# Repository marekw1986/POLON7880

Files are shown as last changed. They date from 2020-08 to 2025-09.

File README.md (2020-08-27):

# POLON 7880

## Overview

This is repository stores modified version of TinyBasic interpreter for 8080 based microcomputers. 
It has been customized to my homemade system, based on Polish clone of mentioned CPU - 
CEMI MCY7880. Original code has been supplemented with I/O routines supporting built-in 
peripherals.

Computer is described on my [Hackaday.io profile](https://hackaday.io/project/161333-polon-7880)

This project is still in development.

## Required tools

You need an [a86 cross assembler](https://github.com/glitchwrks/a85) to asemble this project.

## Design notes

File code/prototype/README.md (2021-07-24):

# POLON 7880

This is code of TinyBsic for prototype version of POLON 7880, wired on prototype board.

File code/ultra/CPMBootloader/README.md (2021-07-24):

# POLON 7880

This is code of TinyBsic for final version of POLON 7880, build on PCBs.

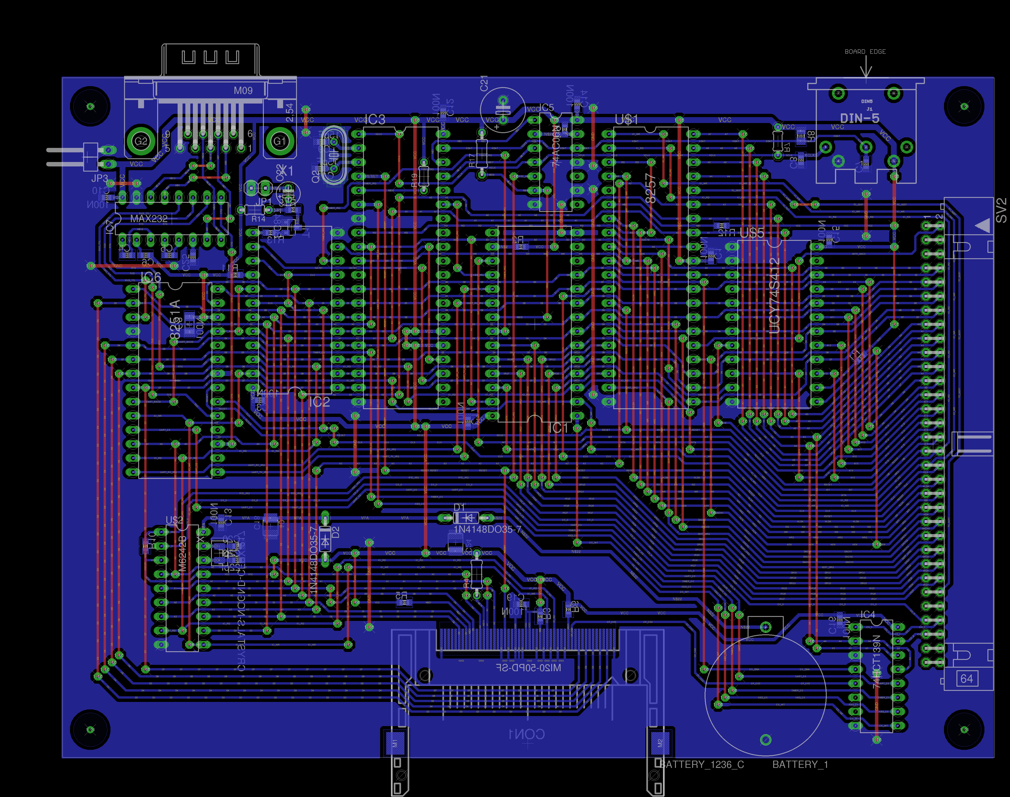
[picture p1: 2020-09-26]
hardware/io/board.png

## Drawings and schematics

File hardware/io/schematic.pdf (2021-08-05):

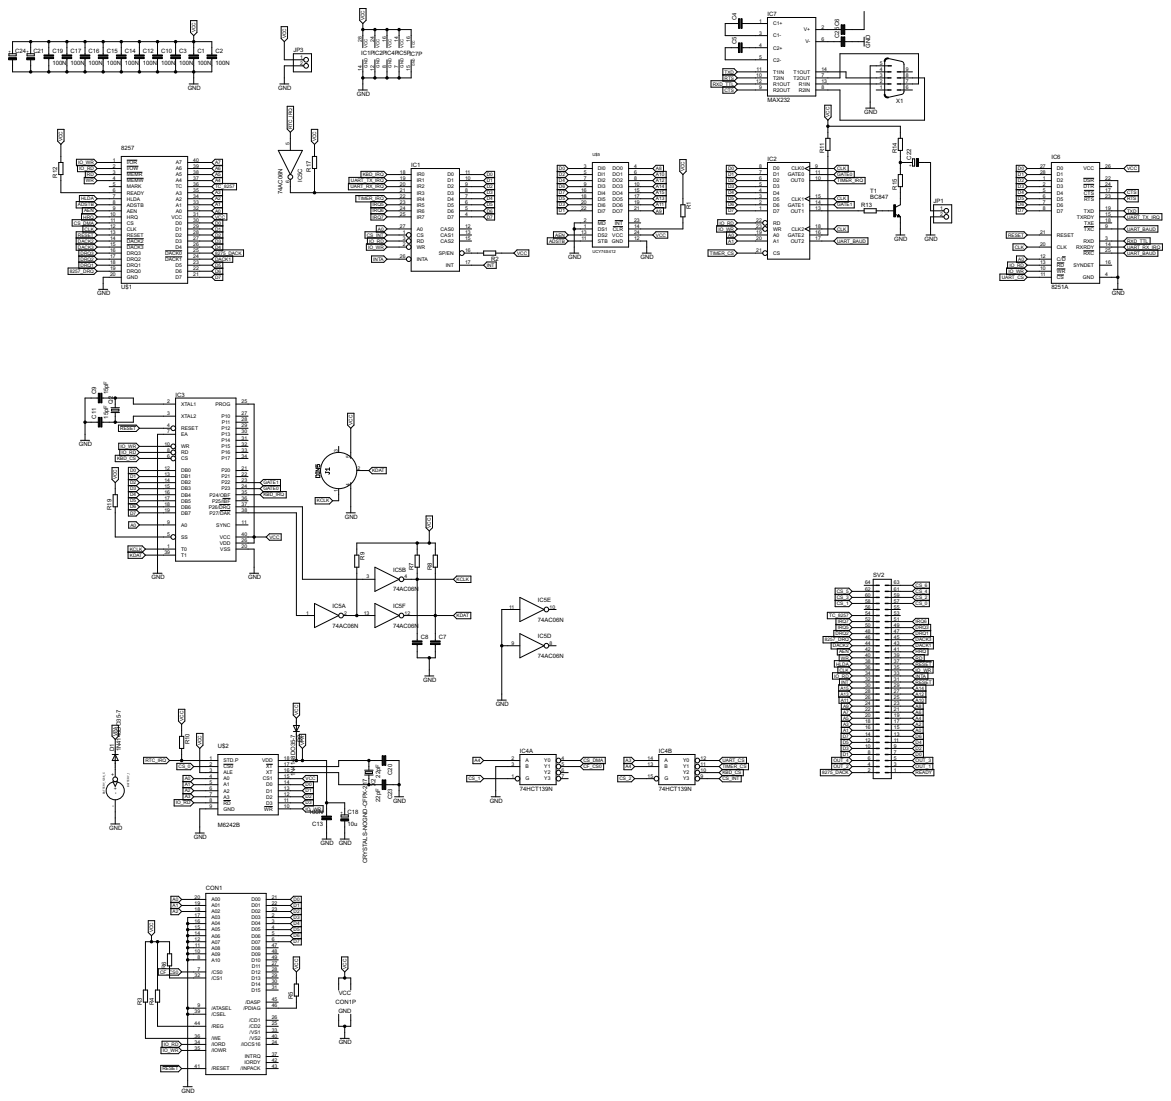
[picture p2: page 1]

8 | 49 D11
7 | 27 D12

32 | 29 D14
9 | 30 D15

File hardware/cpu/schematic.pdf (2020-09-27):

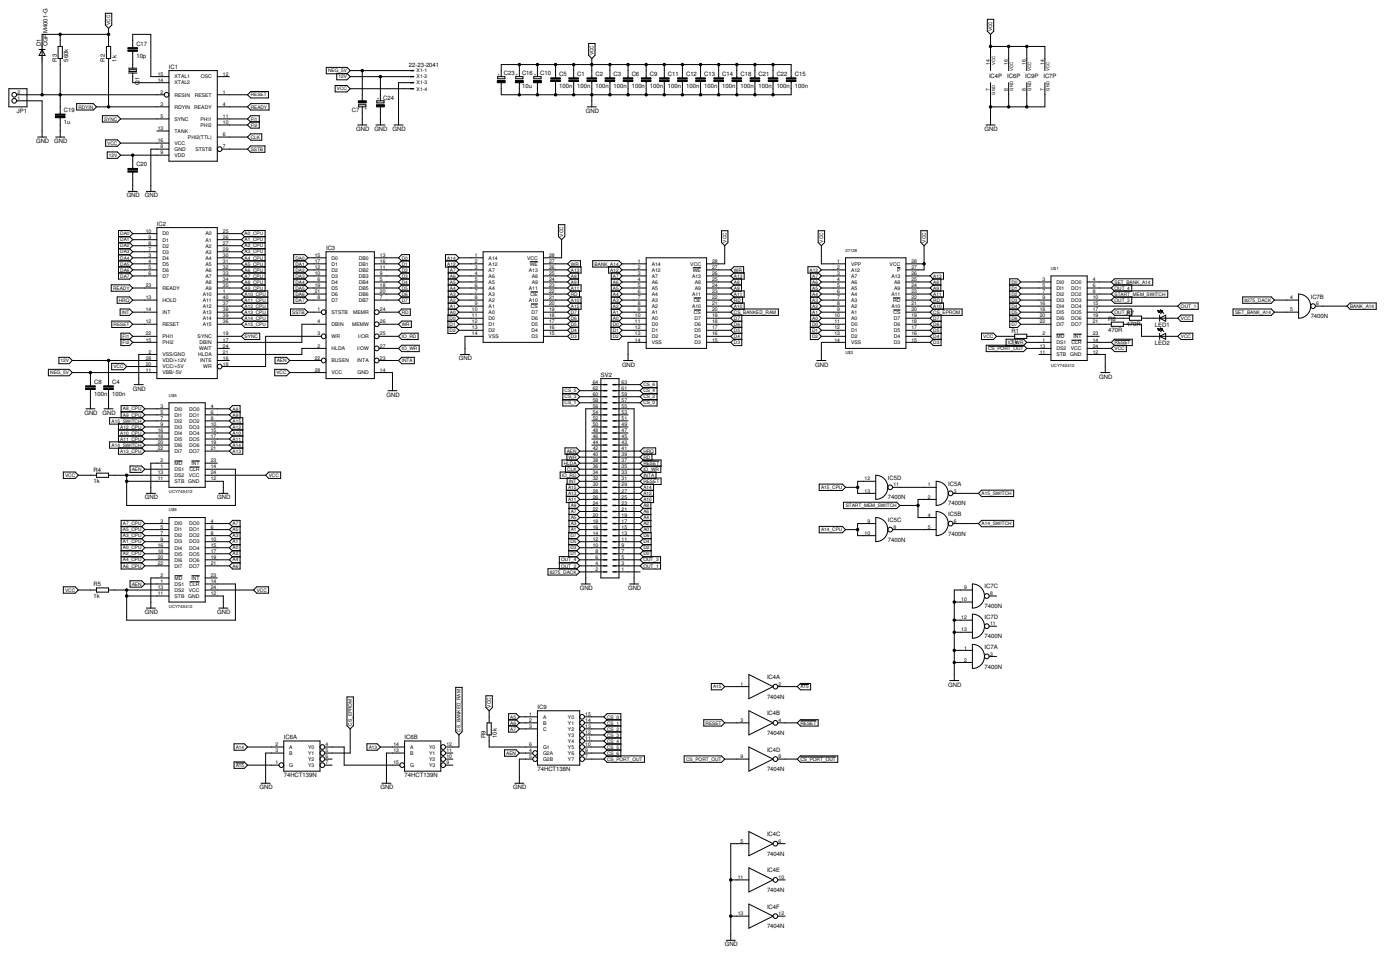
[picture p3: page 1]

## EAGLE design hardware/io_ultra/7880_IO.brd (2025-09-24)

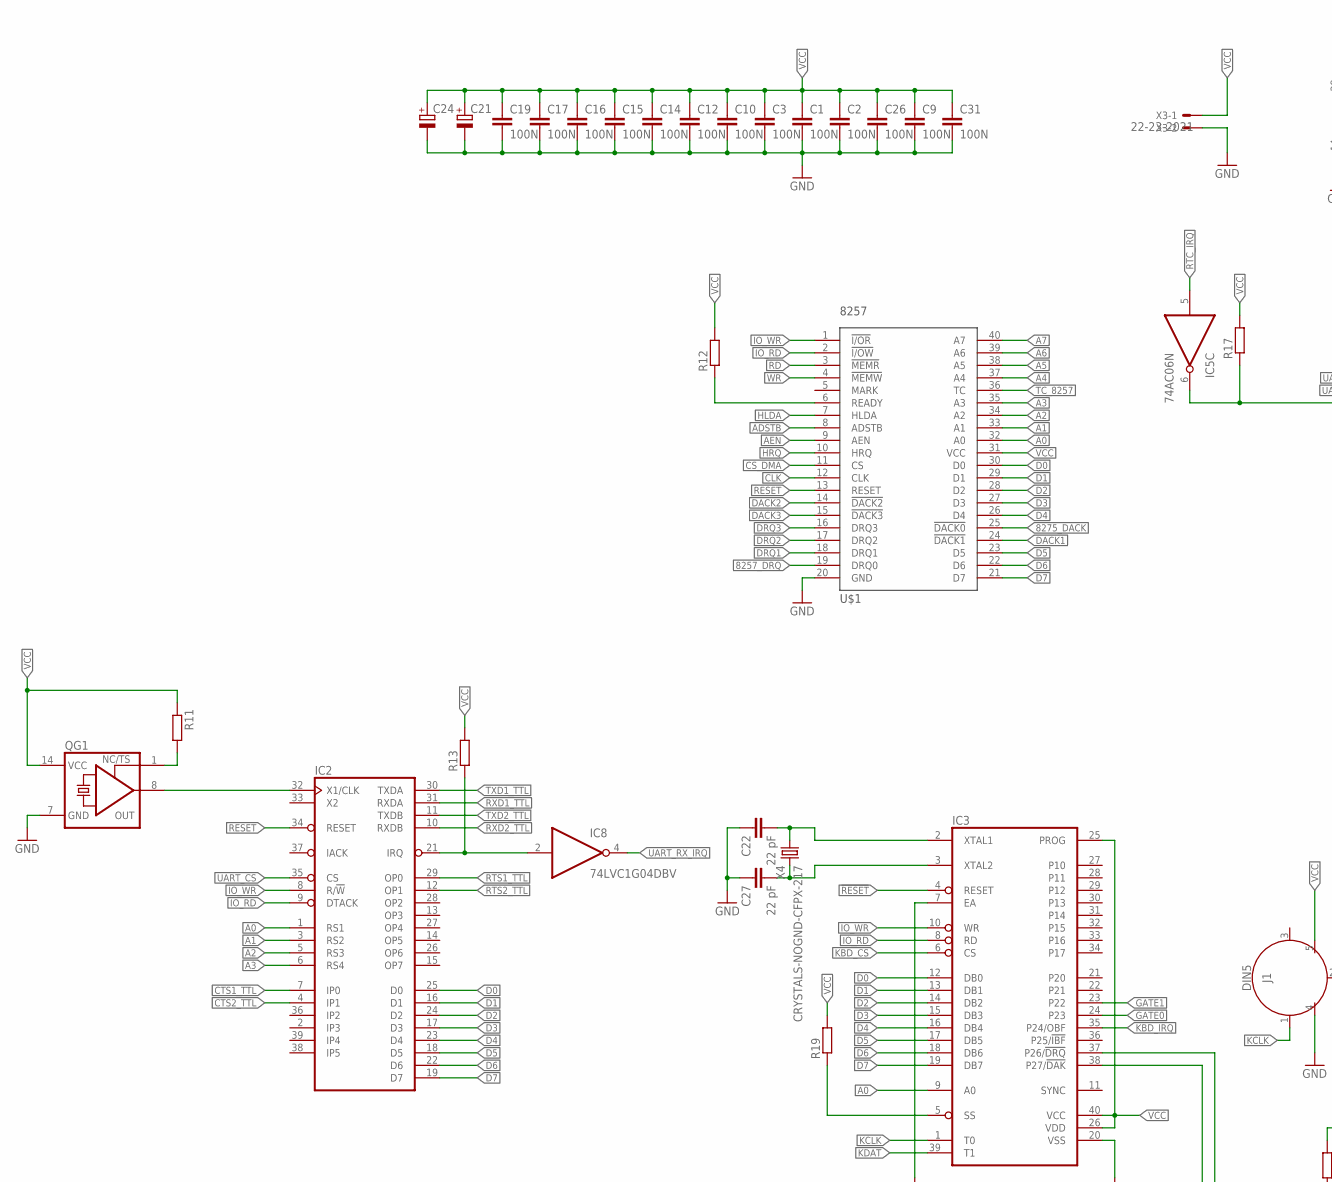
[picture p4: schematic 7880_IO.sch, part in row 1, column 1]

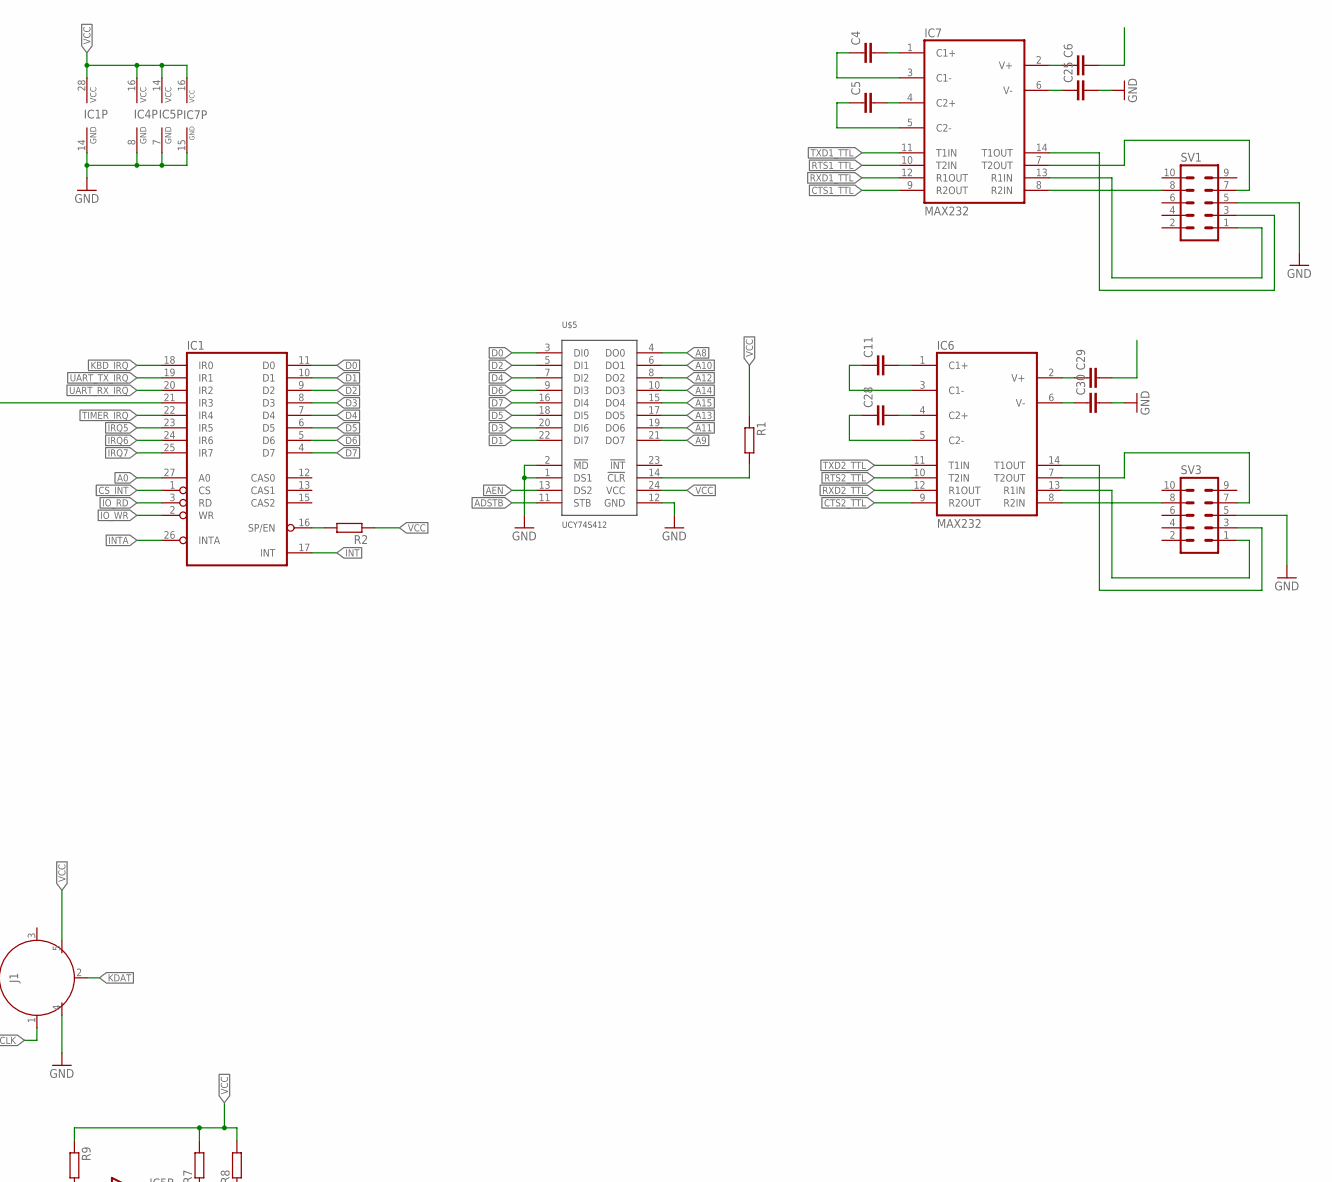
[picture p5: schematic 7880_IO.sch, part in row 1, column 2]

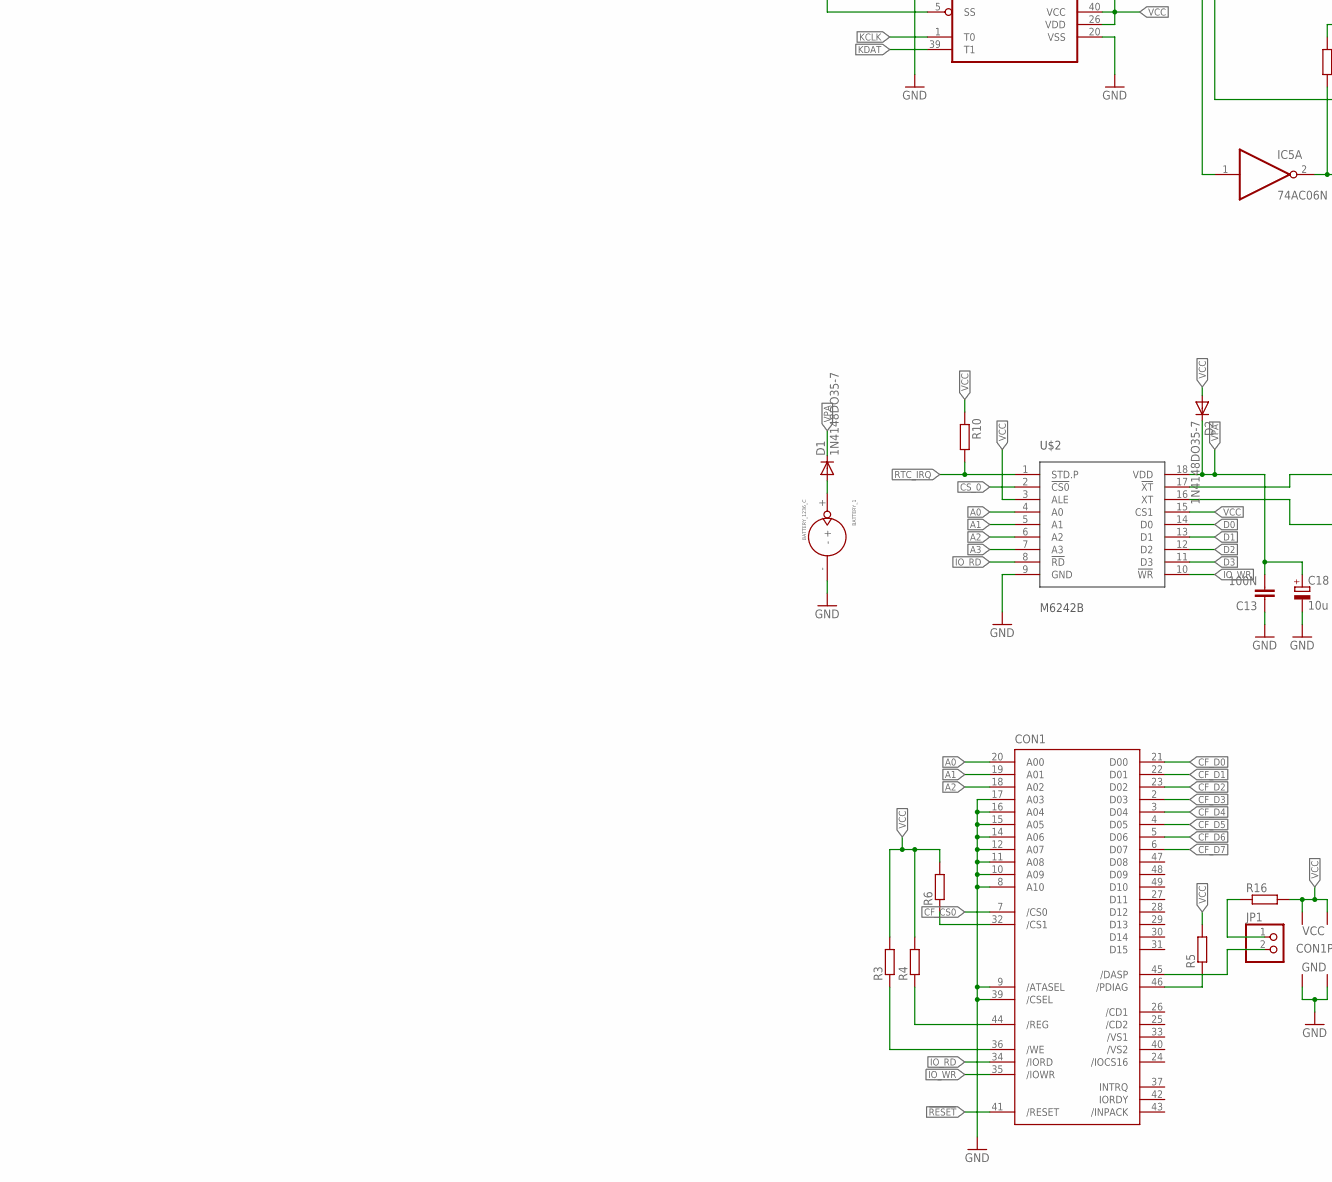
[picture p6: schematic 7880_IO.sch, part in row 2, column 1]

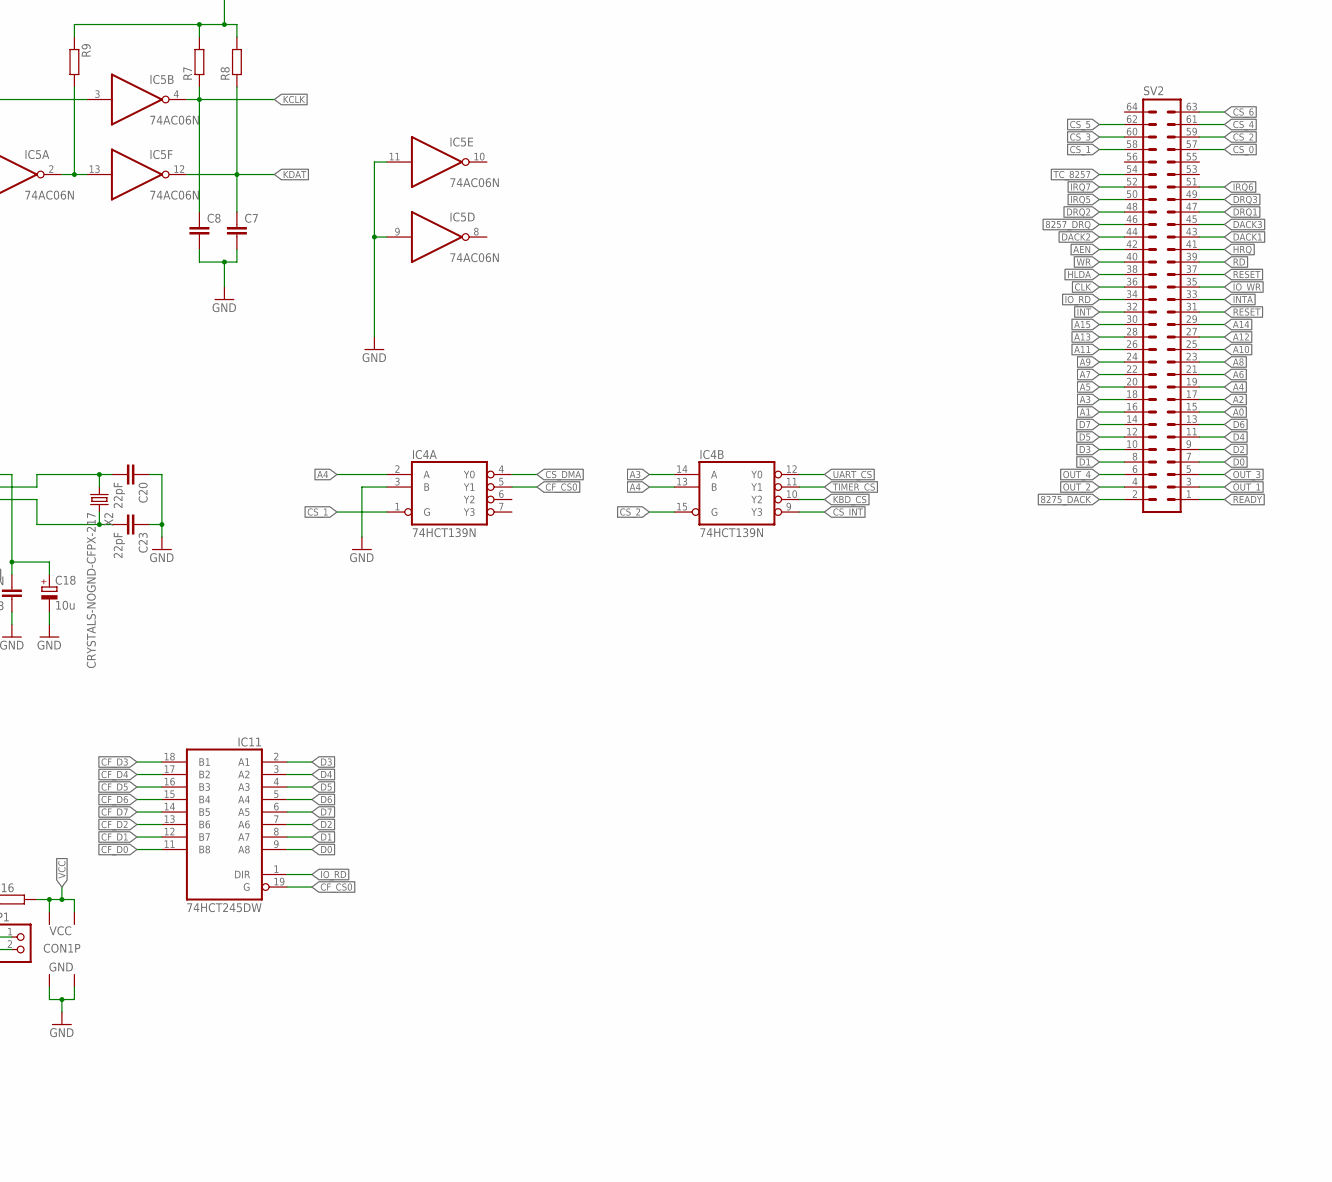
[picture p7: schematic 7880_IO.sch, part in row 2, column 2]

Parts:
BATTERY_1: BATTERY_1236_C
C1, C2, C3, C9, C10, C12, C13, C14, C15, C16, C17, C19, C26, C31: 100N; C0603
C4, C5, C6, C7, C8, C11, C25, C28, C29, C30: C-EUC0603; C0603
C18: 10u; SMC_B
C20, C23: 22pF; C0603
C21: CPOL-EUE3.5-8; E3,5-8
C22, C27: 22 pF; C0603
C24: CPOL-EUSMCB; SMC_B
CON1: CF-CARD-IDE_MODE; MI20-50PD-SF
D1, D2: 1N4148DO35-7; DO35-7
IC1: 8259A; DIL28-6
IC2: MC68681P; DIL40
IC3: UPI-8042AH; DIL40
IC4: 74HCT139N; DIL16
IC5: 74AC06N; DIL14
IC6, IC7: MAX232; DIL16
IC8: 74LVC1G04DBV; SOT23-5
IC11: 74HCT245DW; SO20W
J1: DIN5; DIN5-RA-PTH
JP1: PINHD-1X2; 1X02
QG1: XO-14; DIL14S
R1, R2, R3, R6, R9, R10, R11, R12, R16: R-EU_R0603; R0603
R4, R13, R17: R-EU_0204/7; 0204/7
R5: R-EU_0207/10; 0207/10
R7, R19: R-EU_0204/5; 0204/5
R8: R-EU_M0805; M0805
SV1, SV3: ML10
SV2: ML64L
U$1: 8257; DIL40
U$2: M6242B; DIL18
U$5: UCY74S412; DIL24-6
X2, X4: CRYSTALS-NOGND-CFPX-217; 3.2X1.5-2-PAD
X3: 22-23-2021

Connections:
8257_DRQ: SV2.46, U$1.19 (DRQ0)
8275_DACK: SV2.2, U$1.25 (!DACK0)
2457600HZ: IC2.32 (X1/CLK), QG1.8 (OUT)
!RESET: CON1.41 (/RESET), IC3.4 (RESET), SV2.37
A0: CON1.20 (A00), IC1.27 (A0), IC2.1 (RS1), IC3.9 (A0), SV2.15, U$1.32 (A0), U$2.4 (A0)
A1: CON1.19 (A01), IC2.3 (RS2), SV2.16, U$1.33 (A1), U$2.5 (A1)
A2: CON1.18 (A02), IC2.5 (RS3), SV2.17, U$1.34 (A2), U$2.6 (A2)
A3: IC2.6 (RS4), IC4.14 (A), SV2.18, U$1.35 (A3), U$2.7 (A3)
A4: IC4.2 (A), IC4.13 (B), SV2.19, U$1.37 (A4)
A5: SV2.20, U$1.38 (A5)
A6: SV2.21, U$1.39 (A6)
A7: SV2.22, U$1.40 (A7)
A8: SV2.23, U$5.4 (DO0)
A9: SV2.24, U$5.21 (DO7)
A10: SV2.25, U$5.6 (DO1)
A11: SV2.26, U$5.19 (DO6)
A12: SV2.27, U$5.8 (DO2)
A13: SV2.28, U$5.17 (DO5)
A14: SV2.29, U$5.10 (DO3)
A15: SV2.30, U$5.15 (DO4)
ADSTB: U$1.8 (ADSTB), U$5.11 (STB)
AEN: SV2.42, U$1.9 (AEN), U$5.13 (DS2)
CF_CS0: CON1.7 (/CS0), IC4.5 (Y1), IC11.19 (G)
CF_D0: CON1.21 (D00), IC11.11 (B8)
CF_D1: CON1.22 (D01), IC11.12 (B7)
CF_D2: CON1.23 (D02), IC11.13 (B6)
CF_D3: CON1.2 (D03), IC11.18 (B1)
CF_D4: CON1.3 (D04), IC11.17 (B2)
CF_D5: CON1.4 (D05), IC11.16 (B3)
CF_D6: CON1.5 (D06), IC11.15 (B4)
CF_D7: CON1.6 (D07), IC11.14 (B5)
CLK: SV2.36, U$1.12 (CLK)
COM1_CTS: IC7.8 (R2IN), SV1.8
COM1_RXD: IC7.13 (R1IN), SV1.1
COM1_TXD: IC7.14 (T1OUT), SV1.3
CS_0: SV2.57, U$2.2 (!CS0)
CS_1: IC4.1 (G), SV2.58
CS_2: IC4.15 (G), SV2.59
CS_3: SV2.60
CS_4: SV2.61
CS_5: SV2.62
CS_6: SV2.63
CS_DMA: IC4.4 (Y0), U$1.11 (CS)
CS_INT: IC1.1 (CS), IC4.9 (Y3)
CTS1_TTL: IC2.7 (IP0), IC7.9 (R2OUT)
CTS2_TTL: IC2.4 (IP1), IC6.9 (R2OUT)
D0: IC1.11 (D0), IC2.25 (D0), IC3.12 (DB0), IC11.9 (A8), SV2.7, U$1.30 (D0), U$2.14 (D0), U$5.3 (DI0)
D1: IC1.10 (D1), IC2.16 (D1), IC3.13 (DB1), IC11.8 (A7), SV2.8, U$1.29 (D1), U$2.13 (D1), U$5.22 (DI7)
D2: IC1.9 (D2), IC2.24 (D2), IC3.14 (DB2), IC11.7 (A6), SV2.9, U$1.28 (D2), U$2.12 (D2), U$5.5 (DI1)
D3: IC1.8 (D3), IC2.17 (D3), IC3.15 (DB3), IC11.2 (A1), SV2.10, U$1.27 (D3), U$2.11 (D3), U$5.20 (DI6)
D4: IC1.7 (D4), IC2.23 (D4), IC3.16 (DB4), IC11.3 (A2), SV2.11, U$1.26 (D4), U$5.7 (DI2)
D5: IC1.6 (D5), IC2.18 (D5), IC3.17 (DB5), IC11.4 (A3), SV2.12, U$1.23 (D5), U$5.18 (DI5)
D6: IC1.5 (D6), IC2.22 (D6), IC3.18 (DB6), IC11.5 (A4), SV2.13, U$1.22 (D6), U$5.9 (DI3)
D7: IC1.4 (D7), IC2.19 (D7), IC3.19 (DB7), IC11.6 (A5), SV2.14, U$1.21 (D7), U$5.16 (DI4)
DACK1: SV2.43, U$1.24 (!DACK1)
DACK2: SV2.44, U$1.14 (!DACK2)
DACK3: SV2.45, U$1.15 (!DACK3)
DRQ1: SV2.47, U$1.18 (DRQ1)
DRQ2: SV2.48, U$1.17 (DRQ2)
DRQ3: SV2.49, U$1.16 (DRQ3)
GATE0: IC3.24 (P23)
GATE1: IC3.23 (P22)
GND: BATTERY_1.-, C1.2, C2.2, C3.2, C7.2, C8.2, C9.2, C10.2, C12.2, C13.1, C14.2, C15.2, C16.2, C17.2, C18.-, C19.2, C20.1, C21.-, C22.1, C23.1, C24.-, C25.2, C26.2, C27.1, C30.2, C31.2, CON1.1 (GND1), CON1.8 (A10), CON1.9 (/ATASEL), CON1.10 (A09), CON1.11 (A08), CON1.12 (A07), CON1.14 (A06), CON1.15 (A05), CON1.16 (A04), CON1.17 (A03), CON1.39 (/CSEL), CON1.50 (GND2), IC1.14 (GND), IC2.20 (GND), IC3.7 (EA), IC3.20 (VSS), IC4.3 (B), IC4.8 (GND), IC5.7 (GND), IC5.9 (I), IC5.11 (I), IC6.15 (GND), IC7.15 (GND), IC8.3 (GND), IC11.10 (GND), J1.4, QG1.7 (GND), SV1.5, SV3.5, U$1.20 (GND), U$2.9 (GND), U$5.1 (DS1), U$5.2 (!MD), U$5.12 (GND), X3.2
HLDA: SV2.38, U$1.7 (HLDA)
HRQ: SV2.41, U$1.10 (HRQ)
INT: IC1.17 (INT), SV2.32
INTA: IC1.26 (INTA), SV2.33
IO_RD: CON1.34 (/IORD), IC1.3 (RD), IC2.9 (DTACK), IC3.8 (RD), IC11.1 (DIR), SV2.34, U$1.2 (!I/OW), U$2.8 (!RD)
IO_WR: CON1.35 (/IOWR), IC1.2 (WR), IC2.8 (R/!W), IC3.10 (WR), SV2.35, U$1.1 (!I/OR), U$2.10 (!WR)
IRQ5: IC1.23 (IR5), SV2.50
IRQ6: IC1.24 (IR6), SV2.51
IRQ7: IC1.25 (IR7), SV2.52
KBD_CS: IC3.6 (CS), IC4.10 (Y2)
KBD_IRQ: IC1.18 (IR0), IC3.35 (P24/OBF)
KCLK: C8.1, IC3.1 (T0), IC5.4 (O), J1.1, R7.1
KDAT: C7.1, IC3.39 (T1), IC5.12 (O), J1.2, R8.1
unnamed: R1.2, U$5.14 (!CLR)
unnamed: IC1.16 (SP/EN), R2.2
unnamed: IC3.38 (P27/!DAK), IC5.1 (I)
unnamed: CON1.36 (/WE), R3.1
unnamed: R12.1, U$1.6 (READY)
unnamed: QG1.1 (TS), R11.2
unnamed: IC2.21 (IRQ), IC8.2 (I), R13.1
unnamed: C4.2, IC7.1 (C1+)
unnamed: C5.2, IC7.4 (C2+)
unnamed: C5.1, IC7.5 (C2-)
unnamed: C4.1, IC7.3 (C1-)
unnamed: C6.1, IC7.2 (V+)
unnamed: C25.1, IC7.6 (V-)
unnamed: IC6.7 (T2OUT), SV3.7
unnamed: C11.2, IC6.1 (C1+)
unnamed: IC3.37 (P26/!DRQ), IC5.3 (I)
unnamed: IC7.7 (T2OUT), SV1.7
unnamed: CON1.44 (/REG), R4.1
unnamed: IC5.2 (O), IC5.13 (I), R9.2
unnamed: CON1.46 (/PDIAG), R5.1
unnamed: BATTERY_1.+, D1.A
unnamed: C28.2, IC6.4 (C2+)
unnamed: C28.1, IC6.5 (C2-)
unnamed: CON1.32 (/CS1), R6.1
unnamed: C11.1, IC6.3 (C1-)
unnamed: C29.1, IC6.2 (V+)
unnamed: IC1.21 (IR3), IC5.6 (O), R17.1
unnamed: CON1.45 (/DASP), JP1.2
unnamed: JP1.1, R16.1
unnamed: IC3.5 (SS), R19.1
unnamed: IC6.13 (R1IN), SV3.1
unnamed: IC6.14 (T1OUT), SV3.3
unnamed: IC6.8 (R2IN), SV3.8
unnamed: C30.1, IC6.6 (V-)
OUT_1: SV2.3
OUT_2: SV2.4
OUT_3: SV2.5
OUT_4: SV2.6
RD: SV2.39, U$1.3 (!MEMR)
READY: SV2.1
RESET: IC2.34 (RESET), SV2.31, U$1.13 (RESET)
RTC_IRQ: IC5.5 (I), R10.2, U$2.1 (STD.P)
RTS1_TTL: IC2.29 (OP0), IC7.10 (T2IN)
RTS2_TTL: IC2.12 (OP1), IC6.10 (T2IN)
RXD1_TTL: IC2.31 (RXDA), IC7.12 (R1OUT)
RXD2_TTL: IC2.10 (RXDB), IC6.12 (R1OUT)
SOSCI: C20.2, U$2.17 (!XT), X2.1
SOSCO: C23.2, U$2.16 (XT), X2.2
TC_8257: SV2.54, U$1.36 (TC)
TIMER_CS: IC4.11 (Y1)
TIMER_IRQ: IC1.22 (IR4)
TXD1_TTL: IC2.30 (TXDA), IC7.11 (T1IN)
TXD2_TTL: IC2.11 (TXDB), IC6.11 (T1IN)
UART_CS: IC2.35 (CS), IC4.12 (Y0)
UART_RX_IRQ: IC1.20 (IR2), IC8.4 (O)
UART_TX_IRQ: IC1.19 (IR1)
VCC: C1.1, C2.1, C3.1, C6.2, C9.1, C10.1, C12.1, C14.1, C15.1, C16.1, C17.1, C19.1, C21.+, C24.+, C26.1, C29.2, C31.1, CON1.13 (VCC2), CON1.38 (VCC1), D2.A, IC1.28 (VCC), IC2.40 (VCC), IC3.25 (PROG), IC3.26 (VDD), IC3.40 (VCC), IC4.16 (VCC), IC5.14 (VCC), IC6.16 (VCC), IC7.16 (VCC), IC8.5 (VCC), IC11.20 (VCC), J1.5, QG1.14 (VCC), R1.1, R2.1, R3.2, R4.2, R5.2, R6.2, R7.2, R8.2, R9.1, R10.1, R11.1, R12.2, R13.2, R16.2, R17.2, R19.2, U$1.31 (VCC), U$2.3 (ALE), U$2.15 (CS1), U$5.24 (VCC), X3.1
VPA: C13.2, C18.+, D1.C, D2.C, U$2.18 (VDD)
WR: SV2.40, U$1.4 (!MEMW)
XTAL1: C22.2, IC3.2 (XTAL1), X4.1
XTAL2: C27.2, IC3.3 (XTAL2), X4.2

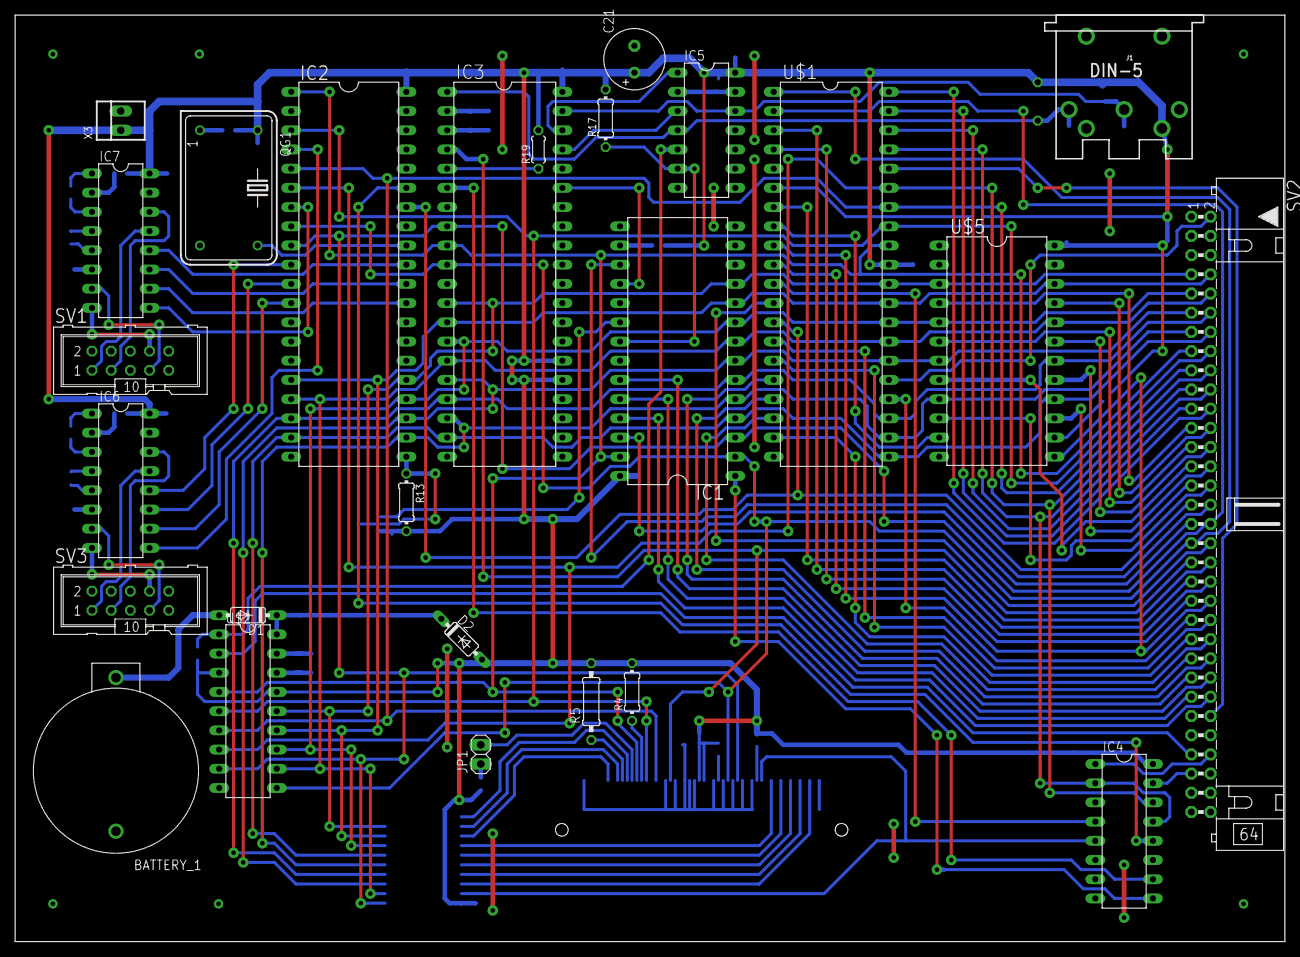
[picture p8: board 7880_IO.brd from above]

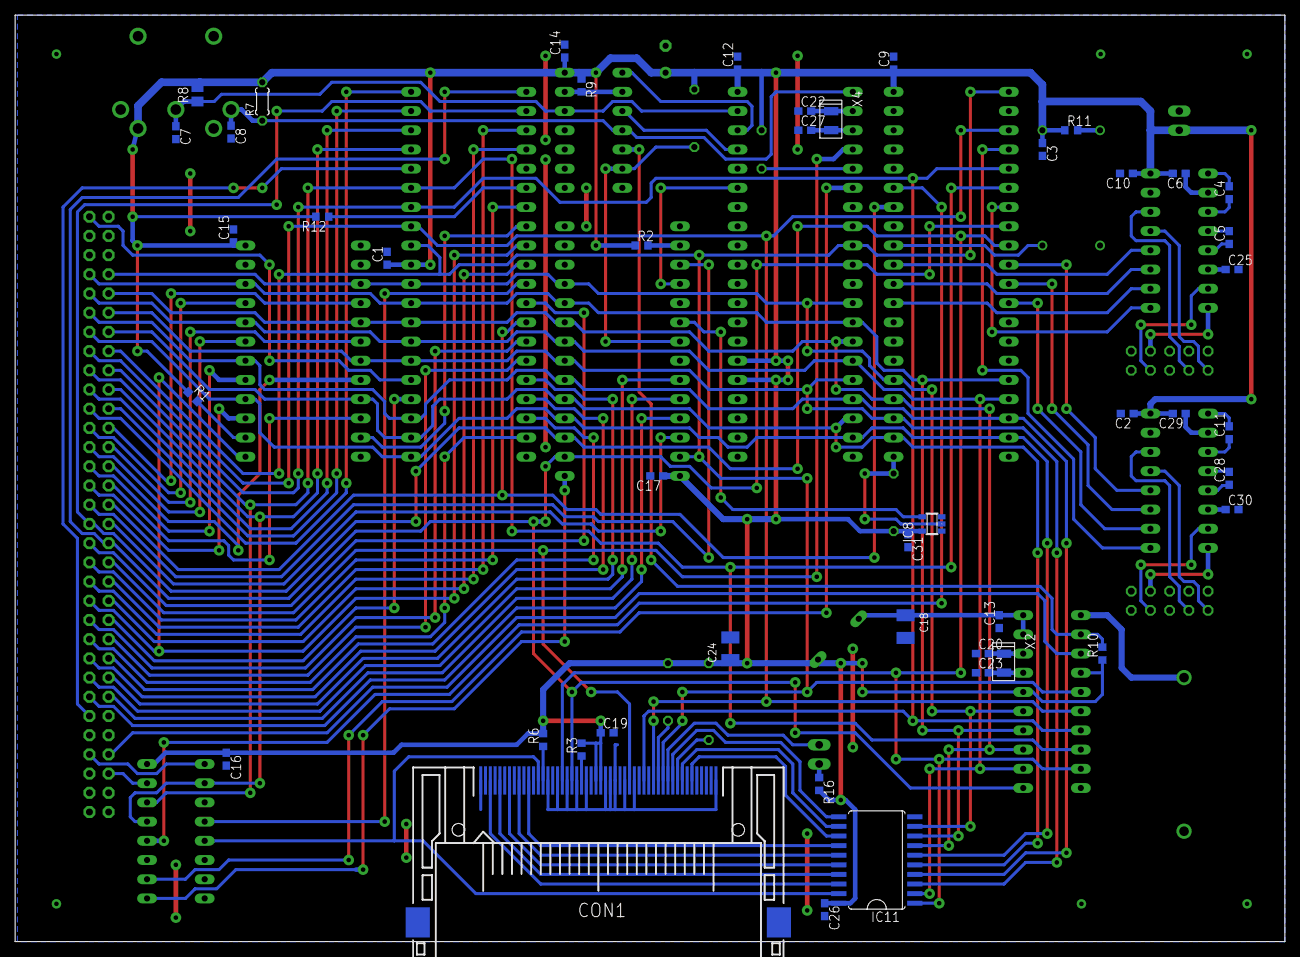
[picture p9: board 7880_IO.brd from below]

Board: 2 copper layers, 167.9 x 122.5 mm, 72 parts (46 on the bottom side), 123 nets.

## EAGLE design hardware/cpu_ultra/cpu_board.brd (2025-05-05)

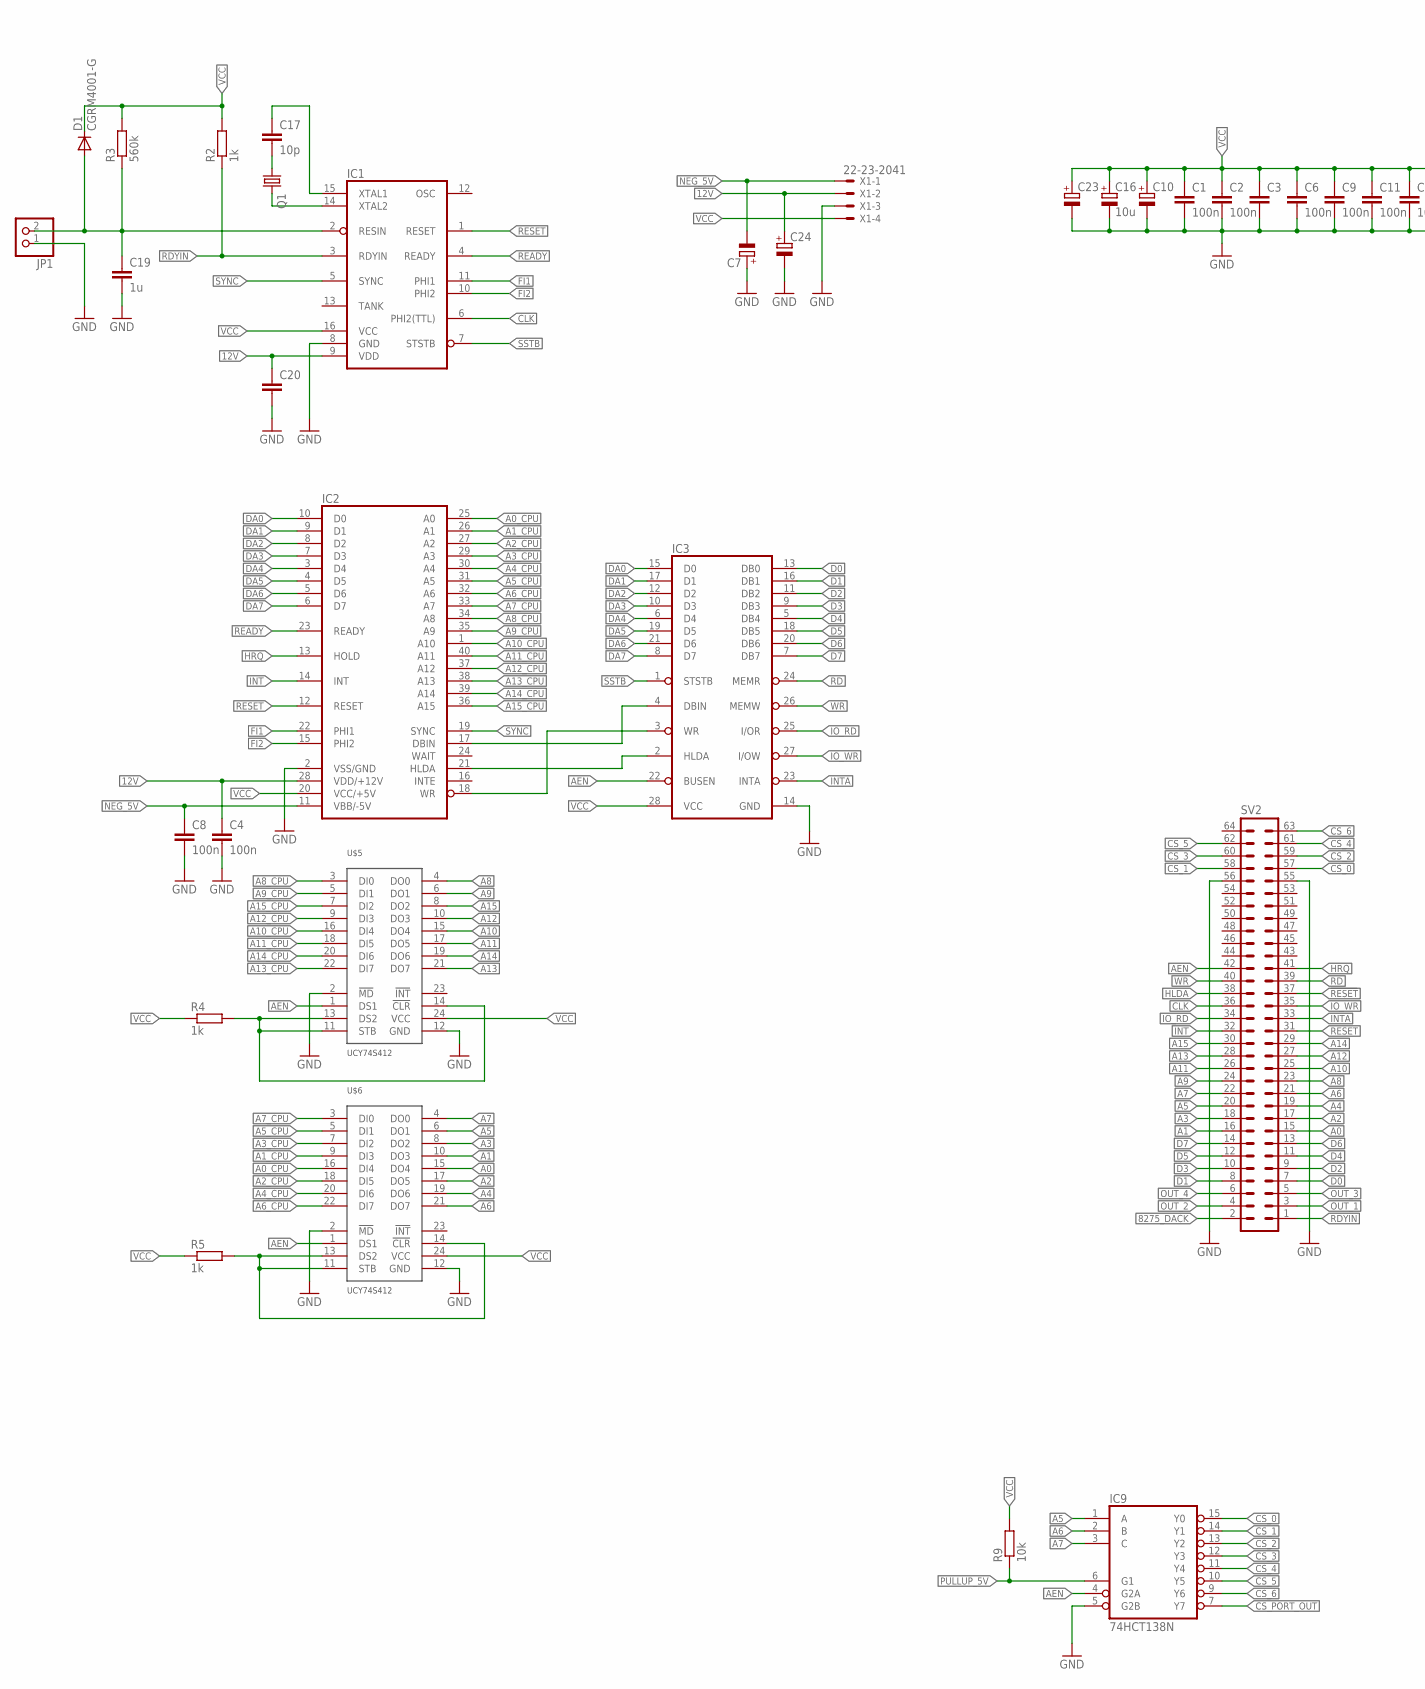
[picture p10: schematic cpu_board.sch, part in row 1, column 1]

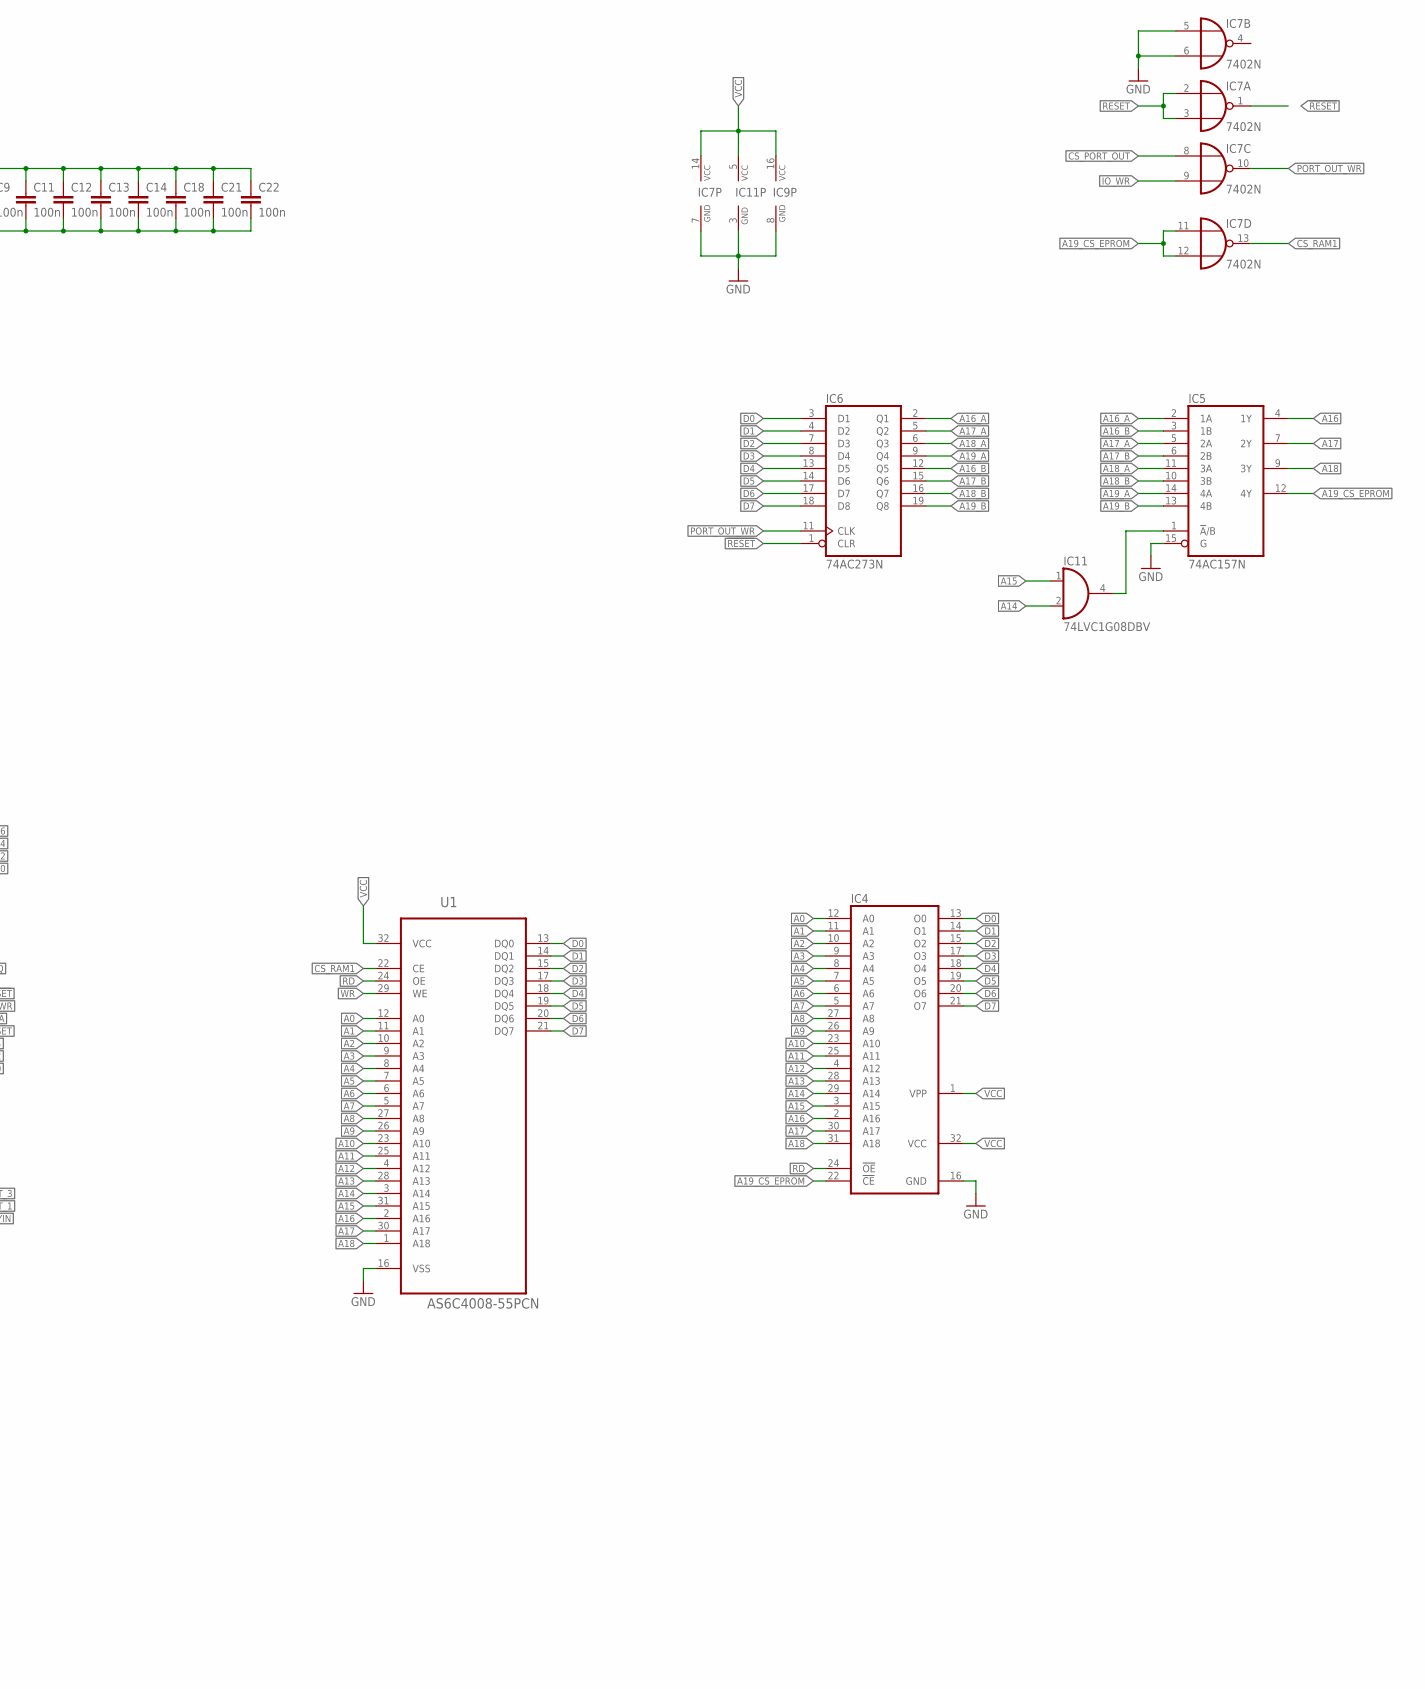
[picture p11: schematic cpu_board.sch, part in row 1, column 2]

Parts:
C1, C2, C4, C6, C8, C21: 100n; C1206
C3, C20: C-EUC0603; C0603
C7: CPOL-EUE2.5-7; E2,5-7
C9, C14, C18, C22: 100n; C0603
C10, C23, C24: CPOL-EUE3.5-8; E3,5-8
C11, C12, C13: 100n; C0805
C16: 10u; SMC_B
C17: 10p; C0603
C19: 1u; C0603
D1: CGRM4001-G; SOD-123_MINI-SMA
IC1: 8224; DIL16
IC2: 8080; DIL40
IC3: 8228; DIL28-6
IC4: 27C4001D; DIL32
IC5: 74AC157N; DIL16
IC6: 74AC273N; DIL20
IC7: 7402N; DIL14
IC9: 74HCT138N; DIL16
IC11: 74LVC1G08DBV; SOT23-5
JP1: PINHD-1X2; 1X02
Q1: CRYSTALHC49U-V; HC49U-V
R2, R4: 1k; R0603
R3: 560k; R0603
R5: 1k; 0204/7
R9: 10k; R0603
SV2: ML64L
U1: AS6C4008-55PCN; DIP254P1524X393-32
U$5, U$6: UCY74S412; DIL24-6
X1: 22-23-2041

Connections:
12V: C4.1, C20.1, C24.+, IC1.9 (VDD), IC2.28 (VDD/+12V), X1.2
8275_DACK: SV2.2
!RESET: IC6.1 (CLR), IC7.1 (O), SV2.37
A0: IC4.12 (A0), SV2.15, U1.12 (A0), U$6.15 (DO4)
A0_CPU: IC2.25 (A0), U$6.16 (DI4)
A1: IC4.11 (A1), SV2.16, U1.11 (A1), U$6.10 (DO3)
A1_CPU: IC2.26 (A1), U$6.9 (DI3)
A2: IC4.10 (A2), SV2.17, U1.10 (A2), U$6.17 (DO5)
A2_CPU: IC2.27 (A2), U$6.18 (DI5)
A3: IC4.9 (A3), SV2.18, U1.9 (A3), U$6.8 (DO2)
A3_CPU: IC2.29 (A3), U$6.7 (DI2)
A4: IC4.8 (A4), SV2.19, U1.8 (A4), U$6.19 (DO6)
A4_CPU: IC2.30 (A4), U$6.20 (DI6)
A5: IC4.7 (A5), IC9.1 (A), SV2.20, U1.7 (A5), U$6.6 (DO1)
A5_CPU: IC2.31 (A5), U$6.5 (DI1)
A6: IC4.6 (A6), IC9.2 (B), SV2.21, U1.6 (A6), U$6.21 (DO7)
A6_CPU: IC2.32 (A6), U$6.22 (DI7)
A7: IC4.5 (A7), IC9.3 (C), SV2.22, U1.5 (A7), U$6.4 (DO0)
A7_CPU: IC2.33 (A7), U$6.3 (DI0)
A8: IC4.27 (A8), SV2.23, U1.27 (A8), U$5.4 (DO0)
A8_CPU: IC2.34 (A8), U$5.3 (DI0)
A9: IC4.26 (A9), SV2.24, U1.26 (A9), U$5.6 (DO1)
A9_CPU: IC2.35 (A9), U$5.5 (DI1)
A10: IC4.23 (A10), SV2.25, U1.23 (A10), U$5.15 (DO4)
A10_CPU: IC2.1 (A10), U$5.16 (DI4)
A11: IC4.25 (A11), SV2.26, U1.25 (A11), U$5.17 (DO5)
A11_CPU: IC2.40 (A11), U$5.18 (DI5)
A12: IC4.4 (A12), SV2.27, U1.4 (A12), U$5.10 (DO3)
A12_CPU: IC2.37 (A12), U$5.9 (DI3)
A13: IC4.28 (A13), SV2.28, U1.28 (A13), U$5.21 (DO7)
A13_CPU: IC2.38 (A13), U$5.22 (DI7)
A14: IC4.29 (A14), IC11.2 (I1), SV2.29, U1.3 (A14), U$5.19 (DO6)
A14_CPU: IC2.39 (A14), U$5.20 (DI6)
A15: IC4.3 (A15), IC11.1 (I0), SV2.30, U1.31 (A15), U$5.8 (DO2)
A15_CPU: IC2.36 (A15), U$5.7 (DI2)
A16: IC4.2 (A16), IC5.4 (1Y), U1.2 (A16)
A16_A: IC5.2 (1A), IC6.2 (Q1)
A16_B: IC5.3 (1B), IC6.12 (Q5)
A17: IC4.30 (A17), IC5.7 (2Y), U1.30 (A17)
A17_A: IC5.5 (2A), IC6.5 (Q2)
A17_B: IC5.6 (2B), IC6.15 (Q6)
A18: IC4.31 (A18), IC5.9 (3Y), U1.1 (A18)
A18_A: IC5.11 (3A), IC6.6 (Q3)
A18_B: IC5.10 (3B), IC6.16 (Q7)
A19_A: IC5.14 (4A), IC6.9 (Q4)
A19_B: IC5.13 (4B), IC6.19 (Q8)
A19_CS_EPROM: IC4.22 (!CE), IC5.12 (4Y), IC7.11 (I0), IC7.12 (I1)
AEN: IC3.22 (BUSEN), IC9.4 (G2A), SV2.42, U$5.1 (DS1), U$6.1 (DS1)
CLK: IC1.6 (PHI2(TTL)), SV2.36
CS_0: IC9.15 (Y0), SV2.57
CS_1: IC9.14 (Y1), SV2.58
CS_2: IC9.13 (Y2), SV2.59
CS_3: IC9.12 (Y3), SV2.60
CS_4: IC9.11 (Y4), SV2.61
CS_5: IC9.10 (Y5), SV2.62
CS_6: IC9.9 (Y6), SV2.63
CS_PORT_OUT: IC7.8 (I0), IC9.7 (Y7)
CS_RAM1: IC7.13 (O), U1.22 (CE)
D0: IC3.13 (DB0), IC4.13 (O0), IC6.3 (D1), SV2.7, U1.13 (DQ0)
D1: IC3.16 (DB1), IC4.14 (O1), IC6.4 (D2), SV2.8, U1.14 (DQ1)
D2: IC3.11 (DB2), IC4.15 (O2), IC6.7 (D3), SV2.9, U1.15 (DQ2)
D3: IC3.9 (DB3), IC4.17 (O3), IC6.8 (D4), SV2.10, U1.17 (DQ3)
D4: IC3.5 (DB4), IC4.18 (O4), IC6.13 (D5), SV2.11, U1.18 (DQ4)
D5: IC3.18 (DB5), IC4.19 (O5), IC6.14 (D6), SV2.12, U1.19 (DQ5)
D6: IC3.20 (DB6), IC4.20 (O6), IC6.17 (D7), SV2.13, U1.20 (DQ6)
D7: IC3.7 (DB7), IC4.21 (O7), IC6.18 (D8), SV2.14, U1.21 (DQ7)
DA0: IC2.10 (D0), IC3.15 (D0)
DA1: IC2.9 (D1), IC3.17 (D1)
DA2: IC2.8 (D2), IC3.12 (D2)
DA3: IC2.7 (D3), IC3.10 (D3)
DA4: IC2.3 (D4), IC3.6 (D4)
DA5: IC2.4 (D5), IC3.19 (D5)
DA6: IC2.5 (D6), IC3.21 (D6)
DA7: IC2.6 (D7), IC3.8 (D7)
FI1: IC1.11 (PHI1), IC2.22 (PHI1)
FI2: IC1.10 (PHI2), IC2.15 (PHI2)
GND: C1.2, C2.2, C3.2, C4.2, C6.2, C7.+, C8.2, C9.2, C10.-, C11.2, C12.2, C13.2, C14.2, C16.-, C18.2, C19.2, C20.2, C21.2, C22.2, C23.-, C24.-, IC1.8 (GND), IC2.2 (VSS/GND), IC3.14 (GND), IC4.16 (GND), IC5.8 (GND), IC5.15 (G), IC6.10 (GND), IC7.5 (I0), IC7.6 (I1), IC7.7 (GND), IC9.5 (G2B), IC9.8 (GND), IC11.3 (GND), JP1.1, SV2.55, SV2.56, U1.16 (VSS), U$5.2 (!MD), U$5.12 (GND), U$6.2 (!MD), U$6.12 (GND), X1.3
HLDA: IC2.21 (HLDA), IC3.2 (HLDA), SV2.38
HRQ: IC2.13 (HOLD), SV2.41
INT: IC2.14 (INT), SV2.32
INTA: IC3.23 (INTA), SV2.33
IO_RD: IC3.25 (I/OR), SV2.34
IO_WR: IC3.27 (I/OW), IC7.9 (I1), SV2.35
unnamed: IC2.17 (DBIN), IC3.4 (DBIN)
unnamed: IC5.1 (!A!/B), IC11.4 (O)
unnamed: IC2.18 (WR), IC3.3 (WR)
unnamed: IC1.14 (XTAL2), Q1.2
unnamed: C17.2, Q1.1
unnamed: C17.1, IC1.15 (XTAL1)
unnamed: C19.1, D1.A, IC1.2 (RESIN), JP1.2, R3.1
unnamed: R5.2, U$6.11 (STB), U$6.13 (DS2), U$6.14 (!CLR)
unnamed: R4.2, U$5.11 (STB), U$5.13 (DS2), U$5.14 (!CLR)
NEG_5V: C7.-, C8.1, IC2.11 (VBB/-5V), X1.1
OUT_1: SV2.3
OUT_2: SV2.4
OUT_3: SV2.5
OUT_4: SV2.6
PORT_OUT_WR: IC6.11 (CLK), IC7.10 (O)
PULLUP_5V: IC9.6 (G1), R9.1
RD: IC3.24 (MEMR), IC4.24 (!OE), SV2.39, U1.24 (OE)
RDYIN: IC1.3 (RDYIN), R2.1, SV2.1
READY: IC1.4 (READY), IC2.23 (READY)
RESET: IC1.1 (RESET), IC2.12 (RESET), IC7.2 (I0), IC7.3 (I1), SV2.31
SSTB: IC1.7 (STSTB), IC3.1 (STSTB)
SYNC: IC1.5 (SYNC), IC2.19 (SYNC)
VCC: C1.1, C2.1, C3.1, C6.1, C9.1, C10.+, C11.1, C12.1, C13.1, C14.1, C16.+, C18.1, C21.1, C22.1, C23.+, D1.C, IC1.16 (VCC), IC2.20 (VCC/+5V), IC3.28 (VCC), IC4.1 (VPP), IC4.32 (VCC), IC5.16 (VCC), IC6.20 (VCC), IC7.14 (VCC), IC9.16 (VCC), IC11.5 (VCC), R2.2, R3.2, R4.1, R5.1, R9.2, U1.32 (VCC), U$5.24 (VCC), U$6.24 (VCC), X1.4
WR: IC3.26 (MEMW), SV2.40, U1.29 (WE)

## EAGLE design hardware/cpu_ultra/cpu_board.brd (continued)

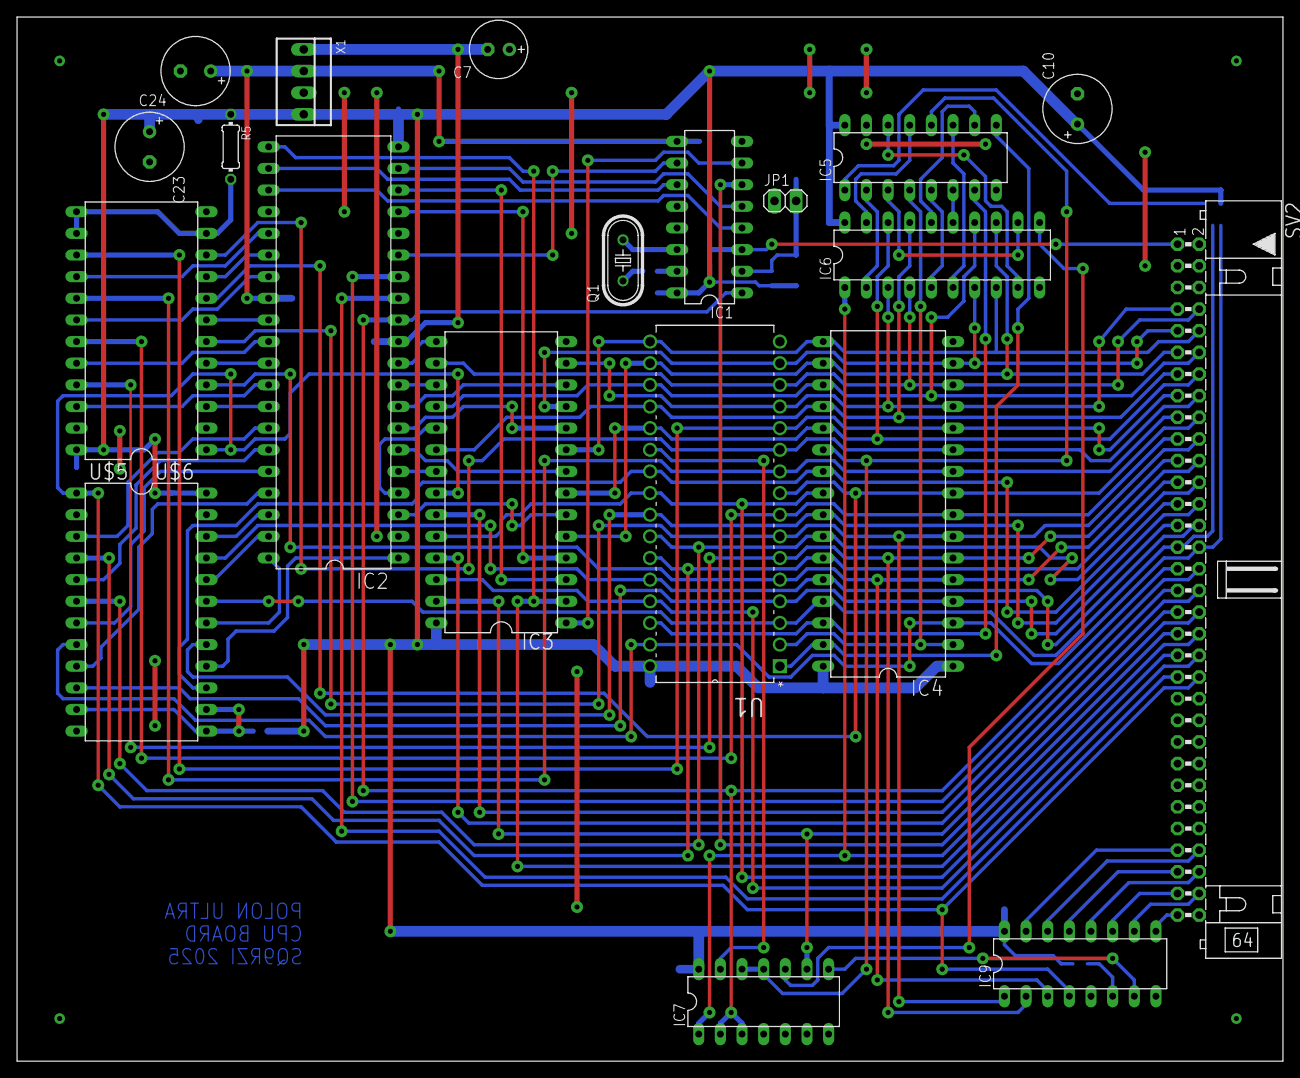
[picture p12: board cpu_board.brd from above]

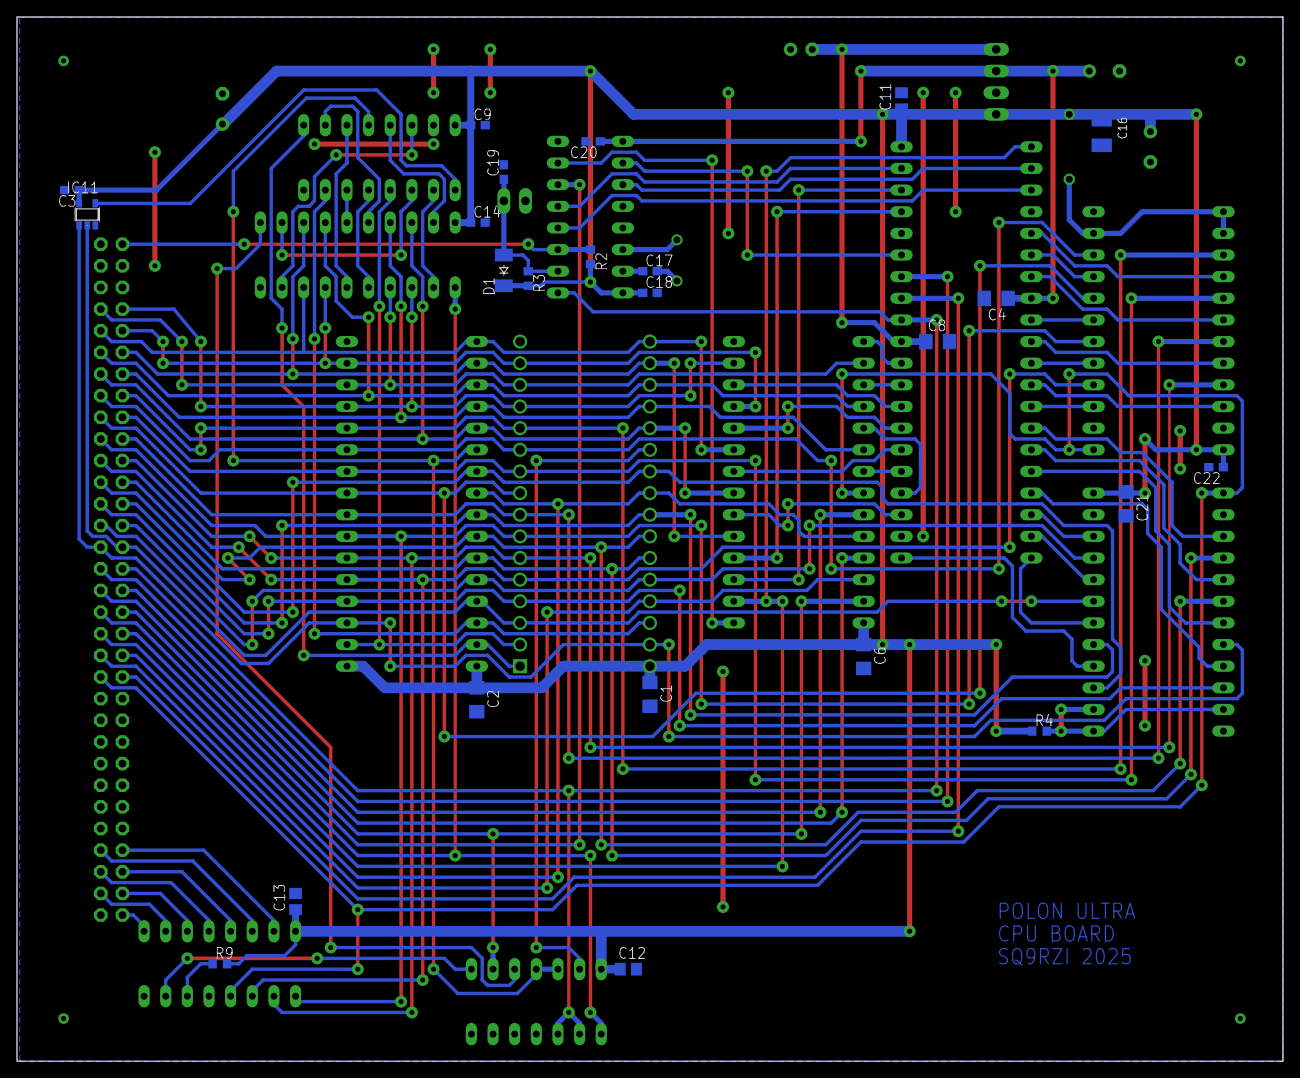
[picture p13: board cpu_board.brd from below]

Board: 2 copper layers, 148.6 x 122.5 mm, 44 parts (24 on the bottom side), 102 nets.

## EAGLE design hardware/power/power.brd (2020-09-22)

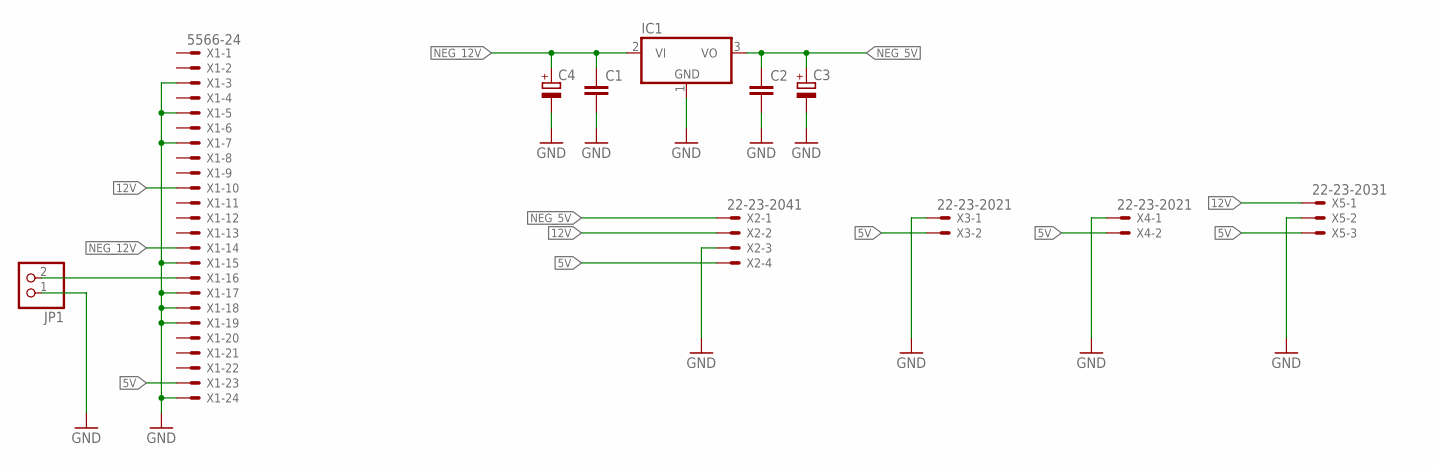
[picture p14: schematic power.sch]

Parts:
C1, C2: C-EUC1206; C1206
C3, C4: CPOL-EUSMCB; SMC_B
IC1: 7905T; TO220H
JP1: PINHD-1X2; 1X02
X1: 5566-24
X2: 22-23-2041
X3, X4: 22-23-2021
X5: 22-23-2031

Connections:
5V: X1.23, X2.4, X3.2, X4.2, X5.3
12V: X1.10, X2.2, X5.1
GND: C1.2, C2.2, C3.-, C4.-, IC1.1 (GND), JP1.1, X1.3, X1.5, X1.7, X1.15, X1.17, X1.18, X1.19, X1.24, X2.3, X3.1, X4.1, X5.2
unnamed: JP1.2, X1.16
NEG_5V: C2.1, C3.+, IC1.3 (VO), X2.1
NEG_12V: C1.1, C4.+, IC1.2 (VI), X1.14

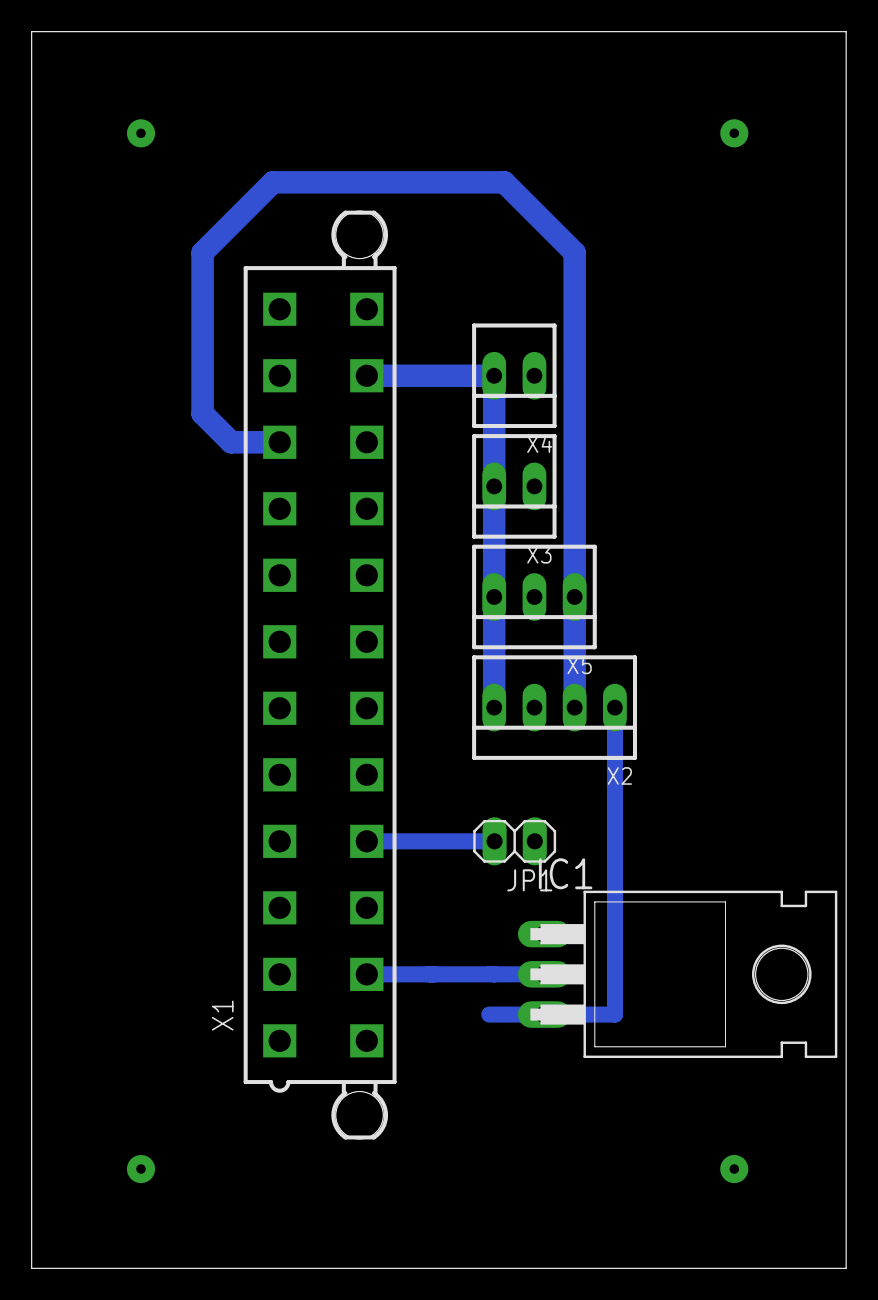
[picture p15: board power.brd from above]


Board: 2 copper layers, 51.4 x 78.1 mm, 11 parts (4 on the bottom side), 6 nets.

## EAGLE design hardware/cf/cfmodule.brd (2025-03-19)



Board: 2 copper layers, 59.1 x 64.8 mm, 10 parts (3 on the bottom side), 30 nets.

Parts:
C1, C19: C0603
C24: SMC_B
CON1: MI20-50PD-SF
E$2: 2X17
E$3: SO20W
R3: R0603
R4, R5: 0204/7
R6: 0204/5

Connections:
A0: CON1.20, E$2.14
A1: CON1.19, E$2.15
A2: CON1.18, E$2.16
CF_CS0: CON1.7, E$2.27, E$3.19
D0: CON1.21, E$3.11
D1: CON1.22, E$3.12
D2: CON1.23, E$3.13
D3: CON1.2, E$3.14
D4: CON1.3, E$3.15
D5: CON1.4, E$3.16
D6: CON1.5, E$3.17
D7: CON1.6, E$3.18
GND: C1.2, C19.2, C24.-, CON1.1, CON1.8, CON1.9, CON1.10, CON1.11, CON1.12, CON1.14, CON1.15, CON1.16, CON1.17, CON1.39, CON1.50, E$2.1, E$2.2, E$2.19, E$2.20, E$2.23, E$2.24, E$2.33, E$2.34, E$3.10
IO_RD: CON1.34, E$2.26, E$3.1
IO_WR: CON1.35, E$2.25
unnamed: CON1.36, R3.1
unnamed: CON1.44, R4.1
unnamed: CON1.46, R5.1
unnamed: CON1.32, R6.1
RST: CON1.41, E$2.18
S$1: E$2.30, E$3.4
S$2: E$2.28, E$3.2
S$8: E$2.13, E$3.9
S$9: CON1.45, E$2.17
S$11: E$2.29, E$3.3
S$12: E$2.31, E$3.5
S$13: E$2.32, E$3.6
S$15: E$2.12, E$3.8
S$16: E$2.11, E$3.7
VCC: C1.1, C19.1, C24.+, CON1.13, CON1.38, E$2.21, E$2.22, E$3.20, R3.2, R4.2, R5.2, R6.2

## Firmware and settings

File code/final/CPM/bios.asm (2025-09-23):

        include "variables.asm"

CCP		EQU	0DC00H   ; was 2200H
BDOS	EQU CCP+806H
BIOS	EQU CCP+1600H
CDISK	EQU	0004H
IOBYTE	EQU 0003H

; WARNING: The following assumes that CPM_BASE%128 = 0
WB_NSECTS	EQU		(BIOS_BOOT-CCP)/128					; number of sectors to load
WB_TRK		EQU		0									; first track now at beginning of partition now
WB_SEC		EQU		(CCP/128)&03H						; first sector number

DEBUG	EQU 0

;**************************************************************
;*
;*        B I O S   J U M P   T A B L E
;*
;**************************************************************
		
		org 0F200H   ; was 3800H
	IF $ != CCP+1600H
		error "BIOS begins at wrong address!"
	ENDIF	
BIOS_BOOT:   JMP      BIOS_BOOT_PROC
BIOS_WBOOT:  JMP      BIOS_WBOOT_PROC
BIOS_CONST:  JMP      BIOS_CONST_PROC
BIOS_CONIN:  JMP      BIOS_CONIN_PROC
BIOS_CONOUT: JMP      BIOS_CONOUT_PROC
BIOS_LIST:   JMP      BIOS_LIST_PROC
BIOS_PUNCH:  JMP      BIOS_PUNCH_PROC
BIOS_READER: JMP      BIOS_READER_PROC
BIOS_HOME:   JMP      BIOS_HOME_PROC
BIOS_SELDSK: JMP      BIOS_SELDSK_PROC
BIOS_SETTRK: JMP      BIOS_SETTRK_PROC
BIOS_SETSEC: JMP      BIOS_SETSEC_PROC
BIOS_SETDMA: JMP      BIOS_SETDMA_PROC
BIOS_READ:   JMP      BIOS_READ_PROC
BIOS_WRITE:  JMP      BIOS_WRITE_PROC
BIOS_PRSTAT: JMP      BIOS_PRSTAT_PROC
BIOS_SECTRN: JMP      BIOS_SECTRN_PROC	

BIOS_BOOT_PROC:
		DI
		LXI  H, BIOS_STACK
		SPHL

        ; Turn on ROM shadowing
		MVI  A, 084H
        OUT  PORT_8212
        NOP
        NOP
        
        ;Initialize 8253
		MVI  A, 30H                     ;TIMER0 - systick
		OUT  CONTR_W_8253               ;Timer 0, write LSB then MSB, mode 0, binary 
		XRA A                     ;LSB, interrupt every 20ms
		OUT  COUNT_REG_0_8253
		MVI  A, 0A0H                    ;MSB, interrupt every 20ms (0xF0 for 30 ms)
		OUT  COUNT_REG_0_8253	
		MVI  A, 0B6H                    ;TIMER2 - baudrate generator for 8251
		OUT CONTR_W_8253                ;Timer 2, write LSB then MSB, mode 3, binary
		MVI  A, 0DH                     ;LSB
		OUT  COUNT_REG_2_8253
		XRA A                     ;MSB
		OUT  COUNT_REG_2_8253          
        ;Initialize 8251
        XRA A
        OUT  UART_8251_CTRL
        XRA A
        OUT  UART_8251_CTRL
        XRA A
        OUT  UART_8251_CTRL
        MVI  A, 40H						;Initiate UART reset
        OUT  UART_8251_CTRL
        MVI	 A, 4EH						;Mode: 8 data, 1 stop, x16
        OUT	 UART_8251_CTRL
        MVI	 A, 37H
        OUT	 UART_8251_CTRL
        
        XRA A
        LXI H, 0000H
        LXI B, CCP
ZERO_LOOP:
        XRA A
        MOV M, A
        INX H
        DCX B
        MOV A, B
        ORA C
        JNZ ZERO_LOOP
        CALL CFGETMBR
        ORA A                     ; Check if MBR loaded properly
        JZ LD_PART_TABLE
        CALL IPUTS
        DB 'MBR load err. Reset required.'
        DB 00H
        CALL ENDLESS_LOOP
LD_PART_TABLE:
        CALL CFLDPARTADDR
CFVAR_INIT:
		XRA A
		STA	CFLBA3
		STA	CFLBA2
		STA	CFLBA1
		STA	CFLBA0
		STA PCFLBA3
		STA PCFLBA2
		STA PCFLBA1
		STA PCFLBA0
		STA CFVAL
	IF DEBUG > 0
	    PUSH PSW
        PUSH B
		PUSH D
		PUSH H
		CALL IPUTS
		DB 'Cold boot procedure entered'
		DB CR
		DB 00H
		POP H
		POP D
		POP B
		POP PSW
	ENDIF
		CALL IPUTS
		DB 'Running CP/M 2.2'
		DB CR
		DB 00H
		CALL IPUTS
		DB 'CRC: '
		DB 00H
		LXI D, CCP
		LXI B, BIOS_STACK_END-CCP
		LXI H, 0000H
CPM_CRC_LOOP:
		LDAX D
		PUSH B
		CALL CRC16_ARC_F
		POP B
		INX D
		DCX B
		MOV A, B
		ORA C
		JNZ CPM_CRC_LOOP
		CALL PRN_ZERO_EX
		MOV A, H
		CALL HEXDUMP_A
		MOV A, L
		CALL HEXDUMP_A
		CALL NEWLINE
		XRA A
		STA IOBYTE
		STA CDISK
;BIOS_TRYKBINIT:								;Reinitialize keyboard
;        CALL BIOS_KBDINIT                        ;Call init routine
;        MOV A, B							;Move result of operation to A
;        CPI 00H								;Check if OK
;        JNZ BIOS_TRYKBINIT						;Retry if not ok. TODO add limit of retries
		JMP GOCPM
	
BIOS_WBOOT_PROC:
		DI
		; We can't just blindly set SP=bios_stack here because disk_read can overwrite it!
		; But we CAN set to use other areas that we KNOW are not currently in use!
		LXI  H, BIOS_WBOOT_STACK		; 
		SPHL
	IF DEBUG > 0
	    PUSH PSW
        PUSH B
		PUSH D
		PUSH H
		CALL IPUTS
		DB 'WBOOT procedure entered'
		DB CR
		DB 00H
		POP H
		POP D
		POP B
		POP PSW
	ENDIF
	IF 0
		CALL IPUTS
		DB 'Wboot not implemented!'
		DB CR
        DB 00H
        JMP $
    ENDIF
		MVI C, 0
		CALL BIOS_SELDSK
		LXI B, WB_TRK
		CALL BIOS_SETTRK
		LXI B, WB_SEC
		CALL BIOS_SETSEC
		LXI B, CCP
		CALL BIOS_SETDMA
		LXI B, WB_NSECTS
BIOS_WBOOT_LOOP:
		PUSH B	; Save remaining sector count
		CALL BIOS_READ
		ORA A
		JZ BIOS_WBOOT_SEC_OK
		CALL IPUTS
		DB 'ERROR: WBOOT FAILED. HALTING.'
		DB CR
		DB '*** PRESS RESET TO REBOOT ***'
		DB CR
		DB 00H
		JMP $
BIOS_WBOOT_SEC_OK:
		; Advance the DMA pointer by 128 bytes
		LHLD DISK_DMA	; HL = last used DMA address
		MOV A, L
		ADI 80H
		MOV L, A
		MOV A, H
		ACI 00H
		MOV H, A
		MOV B, H
		MOV C, L	; BC = HL
		CALL BIOS_SETDMA
		LDA DISK_SECTOR		; A = last used sector number (low byte only for 0..3)
		INR A
		ANI 03H				; if A+1 = 4 then A=0
		JNZ BIOS_WBOOT_SEC	; if A+1 !=4 then do not advance the track number
		; Advance to the next track
		PUSH H
		LHLD DISK_TRACK
		MOV B, H
		MOV C, L
		POP H
		INX B
		CALL BIOS_SETTRK
		XRA A 			; sett A=0 for first sector on new track
BIOS_WBOOT_SEC:
		MVI B, 00H
		MOV C, A
		CALL BIOS_SETSEC
		POP B				; BC = remaining sector counter value
		DCX B				; BC--
		MOV A, B
		ORA C
		JNZ BIOS_WBOOT_LOOP
		; Fall through into GOCPM
GOCPM:
		MVI A, 0C3H ;C3 is a jump instruction
		STA	0		;for JMP to wboot
		LXI H, BIOS_WBOOT	;WBOOT entry point
		SHLD 1		;Set address field for jmp at 0
		
		STA 5		;For JMP to bdos
		LXI H, BDOS	;BDOS entry point
		SHLD 6		;Address field of jump at 5 to bd
		
		; This is here because it is in example CBIOS (AG p. 52)
		LXI H, 0080H	;default DMA address is 80H (TODO! Check!)
		SHLD DISK_DMA
        
		; EI			;Enable interrupts
		LDA CDISK	;Load current disk number
		MOV C, A	;Send to the CCP
		JMP CCP		;Go to the CP/M for further processing
	
BIOS_CONST_PROC:
        IN   UART_8251_CTRL
        NOP                             ;STATUS BIT FLIPPED?
        ANI  RxRDY_MASK                 ;MASK STATUS BIT
		RET
	
BIOS_CONIN_PROC:
        IN   UART_8251_CTRL
        NOP
        ANI  RxRDY_MASK
        JZ BIOS_CONIN_PROC
        IN   UART_8251_DATA
		RET
	
BIOS_CONOUT_PROC:
		PUSH H				; Save content  of HL on original stack, then switch to bios stack
		LXI H, 0000H
		DAD SP	; HL = HL + SP
		SHLD ORIGINAL_SP
		LXI H, BIOS_STACK
		SPHL
		PUSH PSW
		MOV A, C			; Save A on BIOS stack
		CALL OUT_CHAR
		POP PSW			; Restore A from new stack
		LHLD ORIGINAL_SP; Restore original stack
		SPHL
		POP H			; Restore original content of HL	
		RET
		
BIOS_LIST_PROC:
		RET
		  
BIOS_PUNCH_PROC:
		RET
		 
BIOS_READER_PROC:
		MVI A, 1AH
		RET
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

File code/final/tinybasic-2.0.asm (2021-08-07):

;*************************************************************
; 
;                 TINY BASIC FOR INTEL 8080
;                       VERSION 2.0
;                     BY LI-CHEN WANG
;                  MODIFIED AND TRANSLATED
;                    TO INTEL MNEMONICS
;                     BY ROGER RAUSKOLB
;                      10 OCTOBER,1976
;                        @COPYLEFT
;                   ALL WRONGS RESERVED
; 
;*************************************************************
; 
; *** ZERO PAGE SUBROUTINES ***
; 
; THE 8080 INSTRUCTION SET LETS YOU HAVE 8 ROUTINES IN LOW
; MEMORY THAT MAY BE CALLED BY RST N, N BEING 0 THROUGH 7.
; THIS IS A ONE BYTE INSTRUCTION AND HAS THE SAME POWER AS
; THE THREE BYTE INSTRUCTION CALL LLHH.  TINY BASIC WILL
; USE RST 0 AS START AND RST 1 THROUGH RST 7 FOR
; THE SEVEN MOST FREQUENTLY USED SUBROUTINES.
; TWO OTHER SUBROUTINES (CRLF AND TSTNUM) ARE ALSO IN THIS
; SECTION.  THEY CAN BE REACHED ONLY BY 3-BYTE CALLS.
;

PORT_8212   		EQU		0E0H 
UART_8251_DATA    	EQU     40H
UART_8251_CTRL		EQU		41H
PIC_8259_LOW		EQU		58H
PIC_8259_HIGH		EQU		59H
COUNT_REG_0_8253 	EQU 	48H
COUNT_REG_1_8253 	EQU 	49H
COUNT_REG_2_8253 	EQU 	4AH
CONTR_W_8253 		EQU 	4BH
KBD_DATA            EQU     50H
KBD_STATUS          EQU     51H
KBD_CMD             EQU     51H
RTC_1_SEC_REG		EQU		00H
RTC_10_SEC_REG		EQU		01H
RTC_1_MIN_REG		EQU		02H
RTC_10_MIN_REG		EQU		03H
RTC_1_HOUR_REG		EQU		04H
RTC_10_HOUR_REG		EQU		05H
RTC_1_DAY_REG		EQU		06H
RTC_10_DAY_REG		EQU		07H
RTC_1_MON_REG		EQU		08H
RTC_10_MON_REG		EQU		09H
RTC_1_YEAR_REG		EQU		0AH
RTC_10_YEAR_REG		EQU		0BH
RTC_WEEK_REG		EQU		0CH
RTC_CTRLD_REG		EQU		0DH
RTC_CTRLE_REG		EQU		0EH
RTC_CTRLF_REG		EQU		0FH

;8253 config
SEL_COUNTER_0 		EQU 	00H
SEL_COUNTER_1 		EQU 	40H
SEL_COUNTER_2 		EQU 	80H
COUNTER_LATCHING 	EQU 	00H 
RL_MSB_ONLY      	EQU 	20H
RL_LSB_ONLY      	EQU 	10H
RL_LSB_THEN_MSB  	EQU 	30H
MODE_0 				EQU 	00H
MODE_1 				EQU 	02H
MODE_2 				EQU 	04H
MODE_3 				EQU 	06H
MODE_4 				EQU 	08H
MODE_5 				EQU 	0AH
BCD 				EQU 	01H
BIN 				EQU 	00H

TxRDY_MASK   		EQU 	01H
RxRDY_MASK			EQU		02H	

; CF REGS
CFBASE              EQU     090H
CFREG0              EQU     CFBASE+0	;DATA PORT
CFREG1              EQU     CFBASE+1	;READ: ERROR CODE, WRITE: FEATURE
CFREG2              EQU     CFBASE+2	;NUMBER OF SECTORS TO TRANSFER
CFREG3              EQU     CFBASE+3	;SECTOR ADDRESS LBA 0 [0:7]
CFREG4              EQU     CFBASE+4	;SECTOR ADDRESS LBA 1 [8:15]
CFREG5              EQU     CFBASE+5	;SECTOR ADDRESS LBA 2 [16:23]
CFREG6              EQU     CFBASE+6	;SECTOR ADDRESS LBA 3 [24:27 (LSB)]
CFREG7              EQU     CFBASE+7	;READ: STATUS, WRITE: COMMAND

        ORG  0C000H
        JMP  SET_PC
SET_PC:
		MVI  A, 04H 
        OUT  PORT_8212
START:  LXI  H,STACK                   ;*** COLD START ***
		SPHL
        MVI  A,0FFH
        JMP  INIT
;

CFINIT:
		MVI A, 00H
		STA	CFLBA3
		MVI A, 00H
		STA	CFLBA2
		MVI A, 00H
		STA	CFLBA1
		MVI A, 00H
		STA	CFLBA0
        MVI A, 04H
        OUT CFREG7
        CALL CFWAIT
        MVI A, 0E0H		                ;LBA3=0, MASTER, MODE=LBA
        OUT	CFREG6
        MVI A, 01H		                ;8-BIT TRANSFERS
        OUT CFREG1
        MVI A, 0EFH		                ;SET FEATURE COMMAND
        OUT CFREG7
        CALL CFWAIT
        CALL CFCHERR
        RET

CFWAIT:
        IN CFREG7
        ANI 80H                         ;MASK OUT BUSY FLAG
        JNZ CFWAIT
        RET	

CFCHERR:	
        IN CFREG7
        ANI	01H		                    ;MASK OUT ERROR BIT
        JZ	CFNERR
        LXI D, CFMSG1
        CALL PRTSTG
        IN	CFREG1
        MOV L, A
        MVI H, 0H
        MVI C, 4H
        CALL PRTNUM
CFNERR:	
        RET    
            
CFREAD:
        CALL CFWAIT
        IN CFREG7
        ANI	08H	                    ;FILTER OUT DRQ
        JZ CFREADE
        IN CFREG0		            ;READ DATA BYTE
        STAX D
        INX D
        JMP	CFREAD
CFREADE:
        RET
        
CFWRITE:
        CALL CFWAIT
        IN CFREG7
        ANI 08H                     ;FILTER OUT DRQ
        JZ CFWRITEE
        LDAX D
        OUT CFREG0
        INX D
        JMP CFWRITE
CFWRITEE:
        RET
        
CFSLBA:
        LDA CFLBA0		                ;LBA 0
        OUT CFREG3
        LDA CFLBA1		                ;LBA 1
        OUT CFREG4
        LDA CFLBA2		                ;LBA 2
        OUT CFREG5	
        LDA CFLBA3		                ;LBA 3
        ANI 0FH	                        ;FILTER OUT LBA BITS
        ORI 0F0H	                    ;MODE LBA, MASTER DEV
        OUT CFREG6
        RET
        
CFINFO:	
        CALL CFWAIT
        MVI	A, 0ECH	                    ;DRIVE ID COMMAND
        OUT	CFREG7
        LXI	D, BLKDAT
        CALL CFREAD
        ;LDX	#TCRLF
        ;JSR	PDATA
;PRINT SERIAL
        ;LDX	#TSISER
        ;JSR	PDATA
        ;LDX	#BLKDAT+20
        ;LDAB	#20
        ;JSR	PRTRSN
        ;LDX	#TCRLF
        ;JSR	PDATA
;PRINT FIRMWARE REV
        ;LDX	#TSIFW
        ;JSR	PDATA
        ;LDX	#BLKDAT+46
        ;LDAB	#8
        ;JSR	PRTRN
        ;LDX	#TCRLF
        ;JSR	PDATA
;PRINT MODEL NUMBER
        ;LDX	#TSIMOD
        ;JSR	PDATA
        ;LDX	#BLKDAT+54
        ;LDAB	#40
        ;JSR	PRTRN
        ;LDX	#TCRLF
        ;JSR	PDATA
;PRINT LBA SIZE
        ;LDX	#TSILBA
        ;JSR	PDATA
        ;LDX	#BLKDAT+123
        ;JSR	OUT2HS
        ;DEX
        ;DEX
        ;JSR	OUT2HS
        ;DEX
        ;DEX
        ;JSR	OUT2HS
        ;DEX
        ;DEX
        ;JSR	OUT2HS
        ;LDX	#TCRLF
        ;JSR	PDATA
        RET        
        
CFRSECT:
		CALL CFSLBA						;SET LBA
		MVI A, 01H
		OUT	CFREG2						;READ ONE SECTOR
		CALL CFWAIT
		MVI A, 20H						;READ SECTOR COMMAND
		OUT	CFREG7
		LXI	D, BLKDAT
		CALL CFREAD
		CALL CFCHERR
		RET
        
CFWSECT:
        CALL CFSLBA                     ;SET LBA
        MVI A, 01H
        OUT CFREG2                      ;WRITE ONE SECTOR
        CALL CFWAIT
        MVI A, 30H                      ;WRITE SECTOR COMMAND
        OUT CFREG7
        LXI D, BLKDAT
        CALL CFWRITE
        CALL CFCHERR
        RET
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

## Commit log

2020-09-18 PCB added
    [cpu_board.brd, cpu_board.sch, io_board.brd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]
2020-09-22 Power board added
    [power.brd, power.sch]
2020-09-24 Changed to fit current PCB version
2020-09-27 hardware files rearanged
    [cpu_board.brd, cpu_board.sch, io_board.brd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]
2020-09-27 pdf schematic added
2021-07-23 Interrupt test
2021-07-24 PCB project fixed
    [io_board.brd, io_board.sch]
2021-07-24 PCB fixes
    [io_board.brd]
2024-05-10 Printing CF info
2024-05-14 Printing partition table
2024-05-16 Detecting missing CF card
    [tinybasic-2.0.asm]
2024-06-05 VDP newline bug fixed
    [labels.asm]
2024-06-07 Batter printing procedures
2024-06-18 CF module for prorotype
    [cfmodule.brd]
2024-06-18 CF module updated
    [cfmodule.brd]
2024-07-09 Interrupt stack use iptimized
2025-01-01 Buffer added to D0..D7 lined of CF card
    [io_board.brd, io_board.sch]
2025-01-03 CF card driver unified with tested prorotype version
2025-01-03 TinyBasic code unified with tested version from prototype hardware
2025-01-03 Small fix in TinyBasic for prototype hardware
    [tinybasic-2.0.asm]
2025-01-03 CF indidator LED added to IO board
    [io_board.brd, io_board.sch]
2025-02-12 Bug in memory address decoder fixed
    [cpu_board.brd, cpu_board.sch]
2025-02-12 AEN signal connected to memory address decoder
    [cpu_board.brd, cpu_board.sch]
2025-02-12 PCB optimized
    [cpu_board.brd]
2025-02-13 AEN removed from memory address decoder
    [cpu_board.brd, cpu_board.sch]
2025-02-14 Amount of data loaded at CP/M boot reduced also in prototype version
2025-02-14 prototype version stack fix
    [tinybasic-2.0.asm]
2025-03-15 Bug fixed in CF driver
2025-03-15 Bug fixed in CF driver (for final version)
    [labels.asm]
2025-03-18 ROM shadowing version
    [cpu_board.brd, cpu_board.sch]
2025-03-19 ROM shadowed version of PCB modified
    [cpu_board.brd, cpu_board.sch]
2025-03-19 Isolate pramaeter changeg in CPU board
    [cpu_board.brd]
2025-04-24 CP/M bootloader added to replace old version of ROM (bootloader + TinyBasic)
    [bootloader.asm]
2025-05-03 CPU board (ROM shadowing version) fix
    [cpu_board.brd, cpu_board.sch]
2025-05-05 CPU board for ULTRA version (work in progress)
    [cpu_board.brd, cpu_board.sch]
2025-05-05 ULTRA CPU board updatye
    [cpu_board.brd, cpu_board.sch]
2025-05-05 Typo fix
    [cpu_board.brd]
2025-05-05 Bug fixed
    [cpu_board.brd, cpu_board.sch]
2025-05-05 Several bugs fixed
    [cpu_board.brd]
2025-05-05 Minor bug fixed
    [cpu_board.brd]
2025-05-19 I/O board for ultra version (work in progress)
    [7880_IO.brd, 7880_IO.sch]
2025-05-19 I/O ultra board updated
    [7880_IO.brd, 7880_IO.sch]
2025-06-24 UART code modified for ultra version
2025-08-23 Test UART for Ultra version added
2025-09-11 MVI A, 00H replaced with XOR A to preserve memory and CPU cycles
    [bios.asm, blink.asm, blink_ultra.asm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]
2025-09-11 CPI 00H replaced with OR A
    [bios.asm, bootloader.asm, test_keyboard.asm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]
2025-09-11 Revert "CPI 00H replaced with OR A"
    This reverts commit 1968b9d18096c119c25759845871f29568eba181.
    [bios.asm, bootloader.asm, test_keyboard.asm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]
2025-09-11 Revert "MVI A, 00H replaced with XOR A to preserve memory and CPU cycles"
    This reverts commit 6d6722e1f909df7f7adef6c4b3d01f5aa4baf1e8.
    [bios.asm, blink.asm, blink_ultra.asm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]
2025-09-11 MVI A, 00H replaced with XRA A
    [bios.asm, blink.asm, blink_ultra.asm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]
2025-09-11 CPI 00H replaced with ORA A
    [bios.asm, bootloader.asm, test_keyboard.asm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]
2025-09-14 Bug in READ procedure fixed
    [bios.asm]
2025-09-14 MVI A, 0 replaced with XRA A
    [bios.asm]
2025-09-24 I/O board (Ultra version) bug fixes
    [7880_IO.brd, 7880_IO.sch]
2026-06-25 Big fixed in PS2 keyboard driver, regrding handling Shift and Ctrl release

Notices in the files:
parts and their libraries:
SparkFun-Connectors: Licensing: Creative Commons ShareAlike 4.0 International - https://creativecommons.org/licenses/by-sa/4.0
